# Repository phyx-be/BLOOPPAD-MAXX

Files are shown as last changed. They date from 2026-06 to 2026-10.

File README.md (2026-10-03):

# BLOOPAD-MAXX
an illuminated 8x8 keypad with a cheap USB microcontroller.

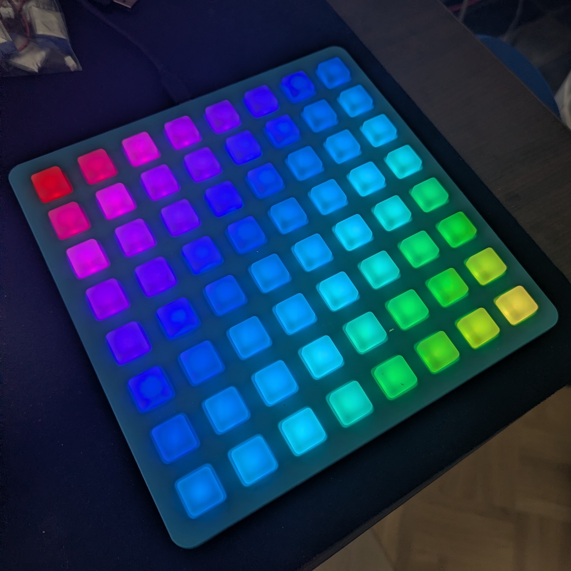
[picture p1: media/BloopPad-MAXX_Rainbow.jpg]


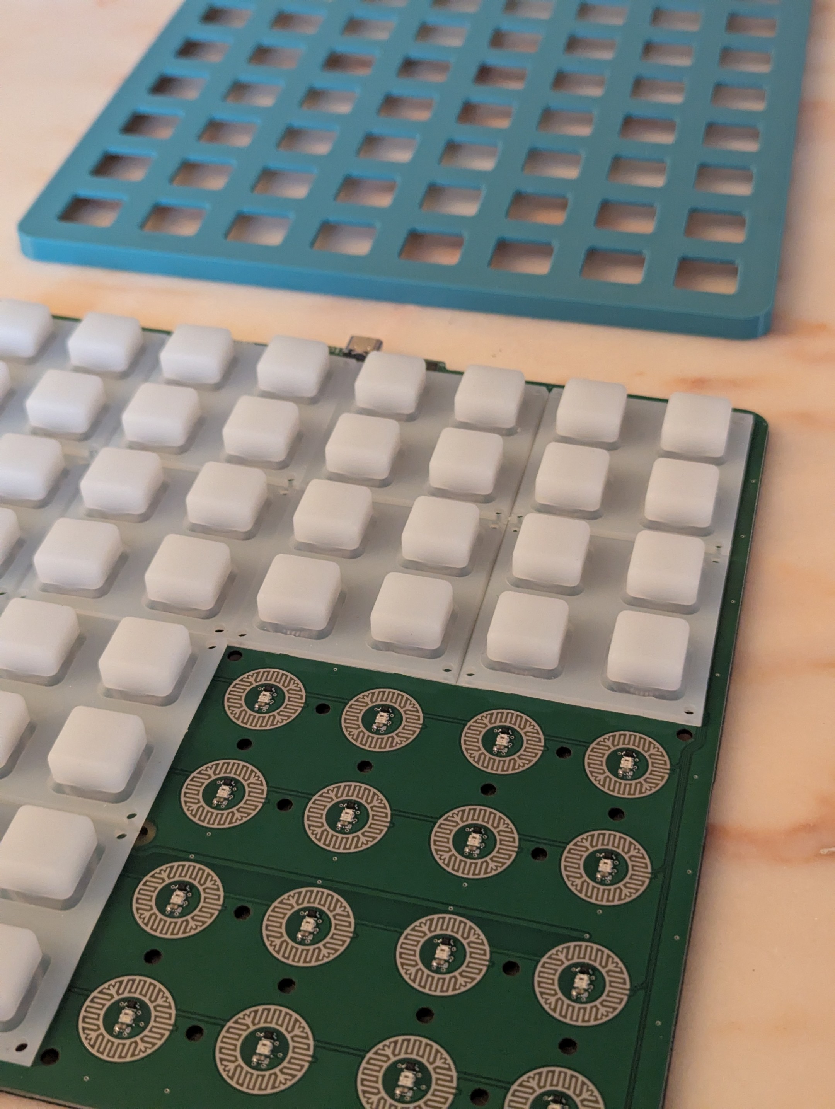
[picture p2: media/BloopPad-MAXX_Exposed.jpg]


## Hardware

There are 4 pins at the top to interact with the microcontroller. The two IO pins (PC18 and PC19) have multiple features, most notable are I²C, UART and SDI (serial 2-wire debug interface). The pins from left to right are as follows:
 * 5V
 * GND
 * PC18 - SDA - DIO - TX3 - PIOC IO0
 * PC19 - SCL - DCK - RX3

> Caution: BloopPad Maxx runs at 5V! So you might need to add a level translator for the I2C pins.

There are 64 WS2812c LEDs, each using around 25–30 mA, so we need around 2A from the host. To request 5V3A from the host, the 5K1 CC resistors are mounted on the USB-C connector. 

> ⚠️⚠️⚠️ The board however has no way of knowing if the USB port can supply that power. So limiting the total brightness of the LEDs might be required!

The button matrix is equiped with diodes to support [n-key rollover](https://en.wikipedia.org/wiki/Key_rollover)

### Rev 00

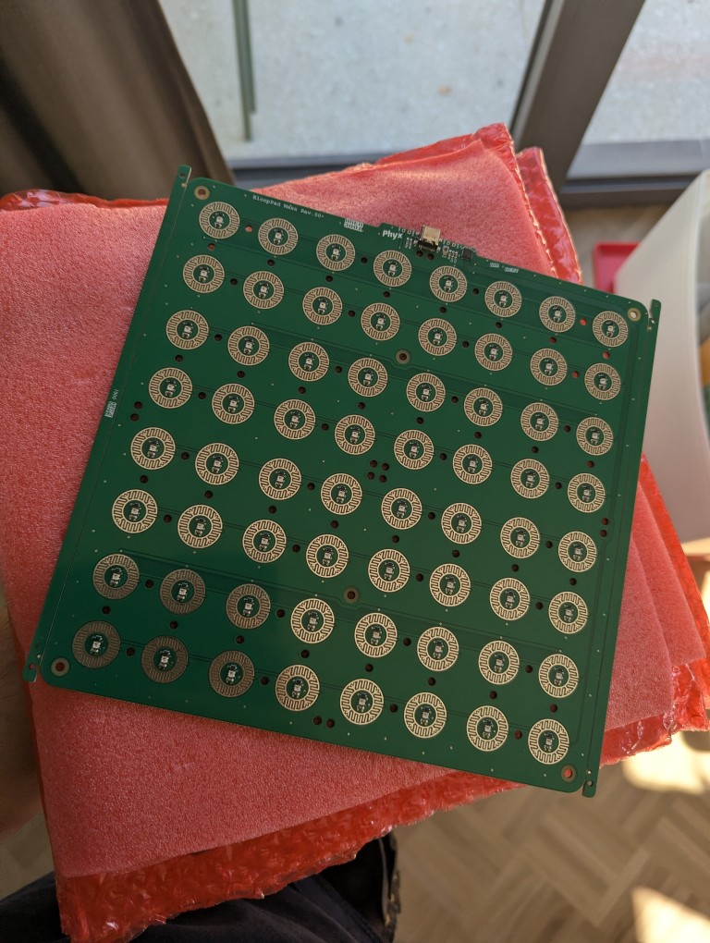
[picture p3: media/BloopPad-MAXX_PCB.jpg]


The initial board design, quickly cobbled together on an evening.

### Rev 01

Moved some traces away from the mounting holes closest to the USB-C connector so metal screws can be used.

## Firmware

This firmware runs on the [CH32X035](https://www.wch-ic.com/products/CH32X035.html) MCU of the BloopPad Maxx.

The firmware handles different functions:
 * Read the button matrix
 * Set the button RGB LEDs
 * Send MIDI CC messages over USB to a PC and over UART
 * Allow control from other devices using I2C (Caution: BloopPad Maxx runs at 5V!)

Please check the [schematics](hardware/BloopPadMaxx_00/OUTPUT/BloopPadMaxx_00.PDF) to get more details about how these peripherals are connected to the CH32X035 MCU.

### MIDI messages

The BloopPad Maxx sends and receives MIDI CC messages through USB or UART (baudrate of `115200 8N1`) to receive the button state or control the LEDs.

The MIDI CC (Control Change) messages related to the buttons are sent every time the state of one of the buttons changes. For each button, the value in the MIDI CC message is `0x7F` when the button is pressed and `0x00` when it is not pressed. Each button has the following CC number assigned:

|  | 0 | 1 | 2 | 3 | 4 | 5 | 6 | 7 |
|-|-|-|-|-|-|-|-|-|
| 0 | 0x00 | 0x01 | 0x02 | 0x03 | 0x04 | 0x05 | 0x06 | 0x07 |
| 1 | 0x10 | 0x11 | 0x12 | 0x13 | 0x14 | 0x15 | 0x16 | 0x17 |
| 2 | 0x20 | 0x21 | 0x22 | 0x23 | 0x24 | 0x25 | 0x26 | 0x27 |
| 3 | 0x30 | 0x31 | 0x32 | 0x33 | 0x34 | 0x35 | 0x36 | 0x37 |
| 4 | 0x40 | 0x41 | 0x42 | 0x43 | 0x44 | 0x45 | 0x46 | 0x47 |
| 5 | 0x50 | 0x51 | 0x52 | 0x53 | 0x54 | 0x55 | 0x56 | 0x57 |
| 6 | 0x60 | 0x61 | 0x62 | 0x63 | 0x64 | 0x65 | 0x66 | 0x67 |
| 7 | 0x70 | 0x71 | 0x72 | 0x73 | 0x74 | 0x75 | 0x76 | 0x77 |

De LEDs beneath the buttons can be controlled by sending a MIDI CC message with a value between 0x01 and 0x0A, which determines the color. Each LED has the following CC number assigned:

|  | 0 | 1 | 2 | 3 | 4 | 5 | 6 | 7 |
|-|-|-|-|-|-|-|-|-|
| 0 | 0x08 | 0x09 | 0x0A | 0x0B | 0x0C | 0x0D | 0x0E | 0x0F |
| 1 | 0x18 | 0x19 | 0x1A | 0x1B | 0x1C | 0x1D | 0x1E | 0x1F |
| 2 | 0x28 | 0x29 | 0x2A | 0x2B | 0x2C | 0x2D | 0x2E | 0x2F |
| 3 | 0x38 | 0x39 | 0x3A | 0x3B | 0x3C | 0x3D | 0x3E | 0x3F |
| 4 | 0x48 | 0x49 | 0x4A | 0x4B | 0x4C | 0x4D | 0x4E | 0x4F |
| 5 | 0x58 | 0x59 | 0x5A | 0x5B | 0x5C | 0x5D | 0x5E | 0x5F |
| 6 | 0x68 | 0x69 | 0x6A | 0x6B | 0x6C | 0x6D | 0x6E | 0x6F |
| 7 | 0x78 | 0x79 | 0x7A | 0x7B | 0x7C | 0x7D | 0x7E | 0x7F |

This is the mapping between the value and the RGB color of the LED to send using a MIDI CC message:

| Value | Red | Green | Blue | Name |
|-|-|-|-|-|
| 0x00 | 0x00 | 0x00 | 0x00 | LED off |
| 0x01 | 0xc5 | 0x0a | 0x08 | orange-red |
| 0x02 | 0x32 | 0xbe | 0x44 | teal |
| 0x03 | 0x42 | 0xd4 | 0xf4 | yellow-green |
| 0x04 | 0xf8 | 0xd2 | 0x00 | warm white |
| 0x05 | 0x00 | 0x44 | 0xff | blue |
| 0x06 | 0xaf | 0x00 | 0xcc | cyan |
| 0x07 | 0xfc | 0xa6 | 0xd7 | white |
| 0x08 | 0xf2 | 0xf2 | 0xff | bright white |
| 0x09 | 0xff | 0x80 | 0x00 | green |

To control the full RGB color of each LED individually using MIDI, we need 4 bytes (LED index, red, green, blue), which is more than the 3 bytes that are available in a Control Change message. That is why we use MIDI System Exclusive (SysEx) messages for this. The format is:

```
F0 13 37 <led> <red> <green> <blue> F7
```

The first byte `0xF0` indicates the start of a SysEx MIDI message. Byte 2 and 3 indicate a manufacturer ID (`0x1337` in our case). The 4th byte is the LED index as described above. The next 3 bytes are the `red`, `green` and `blue` bytes. Their value can be max `0x7F` in a MIDI SysEx message, so make sure you right-shift your RGB data before sending. The last byte `0xF7` indicates the end of the SysEx message.

#### Reboot into the bootloader

One SysEx message is not an LED update:

```
F0 13 37 00 42 4F 4F F7
```

It reboots the pad into WCH's ISP bootloader, so a reflash needs neither the boot button nor a replug - see "Flashing" below. `0x00` sits where an LED frame carries its LED index, and `0x00` is never a valid index (the low nibble of an index is always `8`-`15`), so the two cannot be confused. The trailing `42 4F 4F` ("BOO") makes the command a deliberate eight-byte sequence rather than a short one that might turn up by chance. While the pad is in the bootloader, all LEDs are dim purple.

The command is handled in the game menu and in MIDI mode, not while a game is running. Two cautions:

- **Any MIDI software on the host could send it.** A spurious trigger is recoverable without tools, because the bootloader runs the application again after a few seconds if no upload starts - it costs a reboot, not a brick.
- **The host must start the upload immediately**, for the same reason.

### I2C

The BloopPad Maxx has I2C address `0x55` and uses the following registers to interface/control with its connected peripherals:

| Address (hex) | Name | Access | Bytes | description |
|-|-|-|-|-|
| 0x00 | Version number | R | 3 | Reports the firmware version number |
| 0x03 | Button states | R | 8 | Reports the button states |
| 0x0b | Button RGB LEDs | R/W | 192 | The RGB value of the button leds |

### Building

Use [platformio](https://platformio.org) to build this project. You should install the [ch32v platform package](https://github.com/Community-PIO-CH32V/platform-ch32v) as well. Follow [these instructions](https://pio-ch32v.readthedocs.io/en/latest/installation.html) to do so. If you use the command line, build using:

```
pio run -e debug
```

### Flashing

The easiest way is [the web playground](https://drskunk.github.io/blooppad-maxx-playground/): open its **Flash firmware** panel, connect the pad, and press Flash. It sends the SysEx above to reboot the pad into ISP, then writes and verifies over WebUSB - no boot button, no replug.

From a shell with [wchisp](https://github.com/ch32-rs/wchisp): send `F0 13 37 00 42 4F 4F F7` to the pad with any MIDI tool to put it into ISP, or - if the firmware does not run or does not enumerate - disconnect the USB cable, hold the boot button on the board, and reconnect it. Then run:

```
wchisp flash <path to the firmware.bin file>
```

Or using Platformio:

```
pio run -e debug -t upload
```

## Playing

Beside playing with the built-in apps, you can thinker with the board using the [the web playground](https://drskunk.github.io/blooppad-maxx-playground/) or use it as a sequencer or sample pad on the [Fri3d Scatcher](https://fri3dcamp.github.io/fri3d-scratcher/) website.

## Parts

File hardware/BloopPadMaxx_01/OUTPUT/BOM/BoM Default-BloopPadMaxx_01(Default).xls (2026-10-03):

Bill of Materials |  |  | BloopPad Maxx
Project: |  | BloopPadMaxx_01.PrjPcb
Revision: |  | 01
Variant: |  | Default
Creation Date: | 11/09/2026 | 16:13
Print Date: | 2026-09-11 | 16:13:12
Footprint | Comment | LibRef | Designator | Value | Description | Supplier 1 | Supplier Part Number 1 | Supplier 2 | Supplier Part Number 2 | Supplier 3 | Supplier Part Number 3 | Quantity
C0603_N |  | CAP # 100nF 16V 0603 | C1, C2, C3, C4, C5, C6, C7, C8, C9, C10, C11, C12, C13, C14, C15, C16, C17, C19, C20, C21, C22, C23, C24, C25, C26, C27, C28, C29, C30, C31, C32, C33, C34, C35, C36, C37, C38, C39, C40, C41, C42, C43, C44, C45, C46, C47, C48, C49, C50, C51, C52, C53, C54, C55, C56, C57, C58, C59, C60, C61, C62, C63, C64, C65, C66 | 100nF 16V | CAP # 100nF 16V 0603 | LCSC | C282519 |  |  | Generic | 100nF 16V 0603 X7R | 65
C0603_N |  | CAP # 1uF 16V 0603 | C18 | 1uF 16V | CAP # 1uF 16V 0603 | Farnell | 2320814 | LCSC | C1592 | Generic | 1uF 16V 0603 X7R | 1
CZ20_4x4 | Campzone 2020 4x4 silicone keypad | SW # CZ20 4x4 | CZ1, CZ2, CZ3, CZ4 | CZ20 4x4 | SW # CZ20 4x4 | STOCK |  |  |  |  |  | 4
LED_2022_WS2812B | WS2812 based digital RGB LED 2022 package | LED # RGB WS2812B-2022 | D1, D2, D3, D4, D69, D70, D71, D72, D73, D74, D75, D76, D77, D78, D79, D80, D81, D82, D83, D84, D85, D86, D87, D88, D89, D90, D91, D92, D93, D94, D95, D96, D97, D98, D99, D100, D101, D102, D103, D104, D105, D106, D107, D108, D109, D110, D111, D112, D113, D114, D115, D116, D117, D118, D119, D120, D121, D122, D123, D124, D125, D126, D127, D128 | WS2812B-2022 | LED # RGB WS2812B-2022 | LCSC | C965555 |  |  |  |  | 64
SOD-323_AC | 1N4148W 75V 200mA 1.25Vf@150mA | DIO # 1N4148W SOD-323 | D5, D6, D7, D8, D9, D10, D11, D12, D13, D14, D15, D16, D17, D18, D19, D20, D21, D22, D23, D24, D25, D26, D27, D28, D29, D30, D31, D32, D33, D34, D35, D36, D37, D38, D39, D40, D41, D42, D43, D44, D45, D46, D47, D48, D49, D50, D51, D52, D53, D54, D55, D56, D57, D58, D59, D60, D61, D62, D63, D64, D65, D66, D67, D68 | 1N4148W | DIO # 1N4148W SOD-323 | LCSC | C2904852 | LCSC | C917117 | LCSC | C909968 | 64
XUNPU-TYPEC-304S-ACP16 | USB 2.0 C Reversible Receptacle Horizontal full SMD | USB # C 2.0 RCPT TYPEC-304S-ACP16 | J1 | TYPEC-304S-ACP16 | USB # C 2.0 RCPT TYPEC-304S-ACP16 | LCSC | C5187472 | LCSC | C2927040 | LCSC | C5156603 | 1
R0603_N |  | RES # 10K 0603 | R1 | 10K | RES # 10K 0603 | Farnell | 2502397 | LCSC | C25804 | Generic | 10K 1% 0603 | 1
R0603_N |  | RES # 5K1 0603 | R2, R3 | 5K1 | RES # 5K1 0603 | Farnell | 2845922 | LCSC | C112314 | Generic | 5K1 1% 0603 | 2
OMR_B3U-1000P | LP SMD tact sw 3x2.5mm | SW # TACT mini 3x2.5 mm B3U-1000P | SW1 | B3U-1000P | SW # TACT mini 3x2.5 mm B3U-1000P | LCSC | C561514 | LCSC | C231329 | Digi-Key | SW1020CT-ND | 1
QFN_28_4.0x4.0_P0.4 | WCH CH32X035G8U6 QFN28 RISC-V 32-bit MCU, 62KB Flash, 10KB RAM, USB PD | RISCV # CH32X035G8U6 | U1 | CH32X035G8U6 | RISCV # CH32X035G8U6 | LCSC | C7437027 |  |  |  |  | 1
 |  |  |  |  |  |  |  |  |  |  |  | 204
Approved |  | Notes

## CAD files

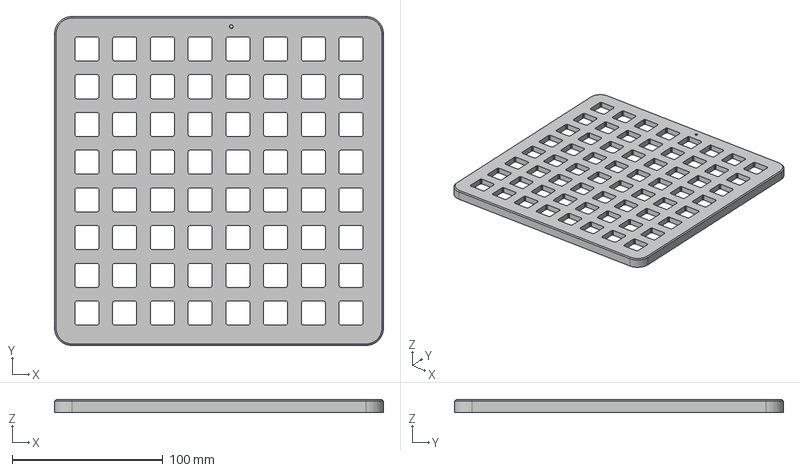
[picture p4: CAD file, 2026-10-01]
mechanical/BloopPadMaxx_00_inserts.step
218.0 x 218.0 x 8.60 mm
TopCover
BottomCover

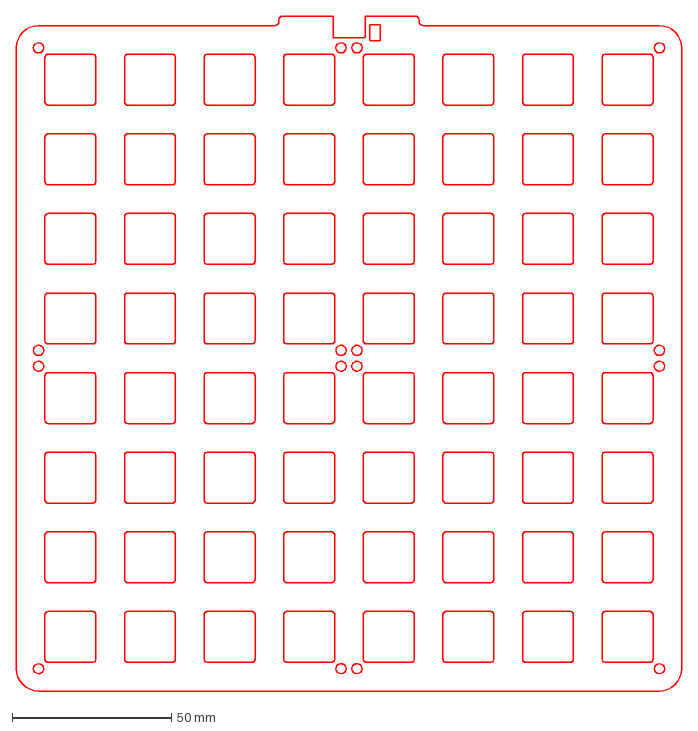
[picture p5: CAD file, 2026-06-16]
mechanical/Top_Cover.dxf
209.0 x 212.0 mm

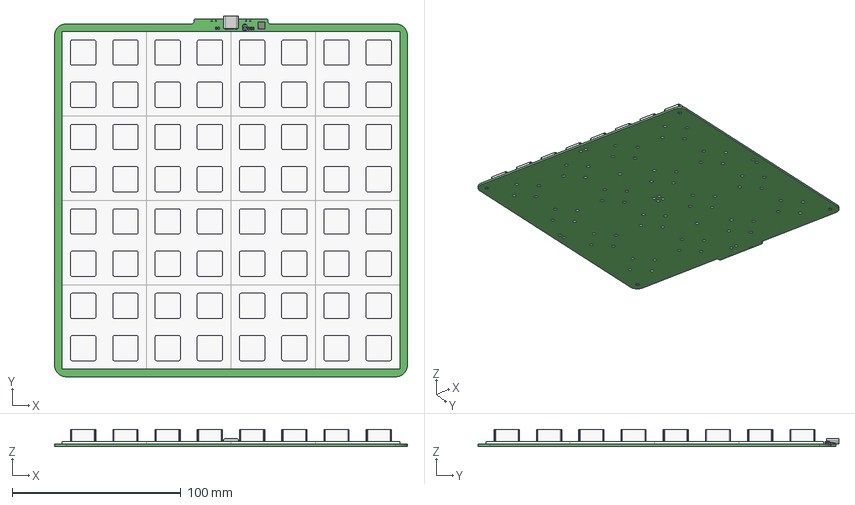
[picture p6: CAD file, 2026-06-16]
mechanical/BloopPadMaxx_00.step
209.0 x 213.5 x 10.3 mm
Extruded x 464
B3U-1000P
Thermal Shape
R0603 x 3
HRO TYPE-C-31-M-12
User Library-SOD323-1 x 64
C0603 x 66

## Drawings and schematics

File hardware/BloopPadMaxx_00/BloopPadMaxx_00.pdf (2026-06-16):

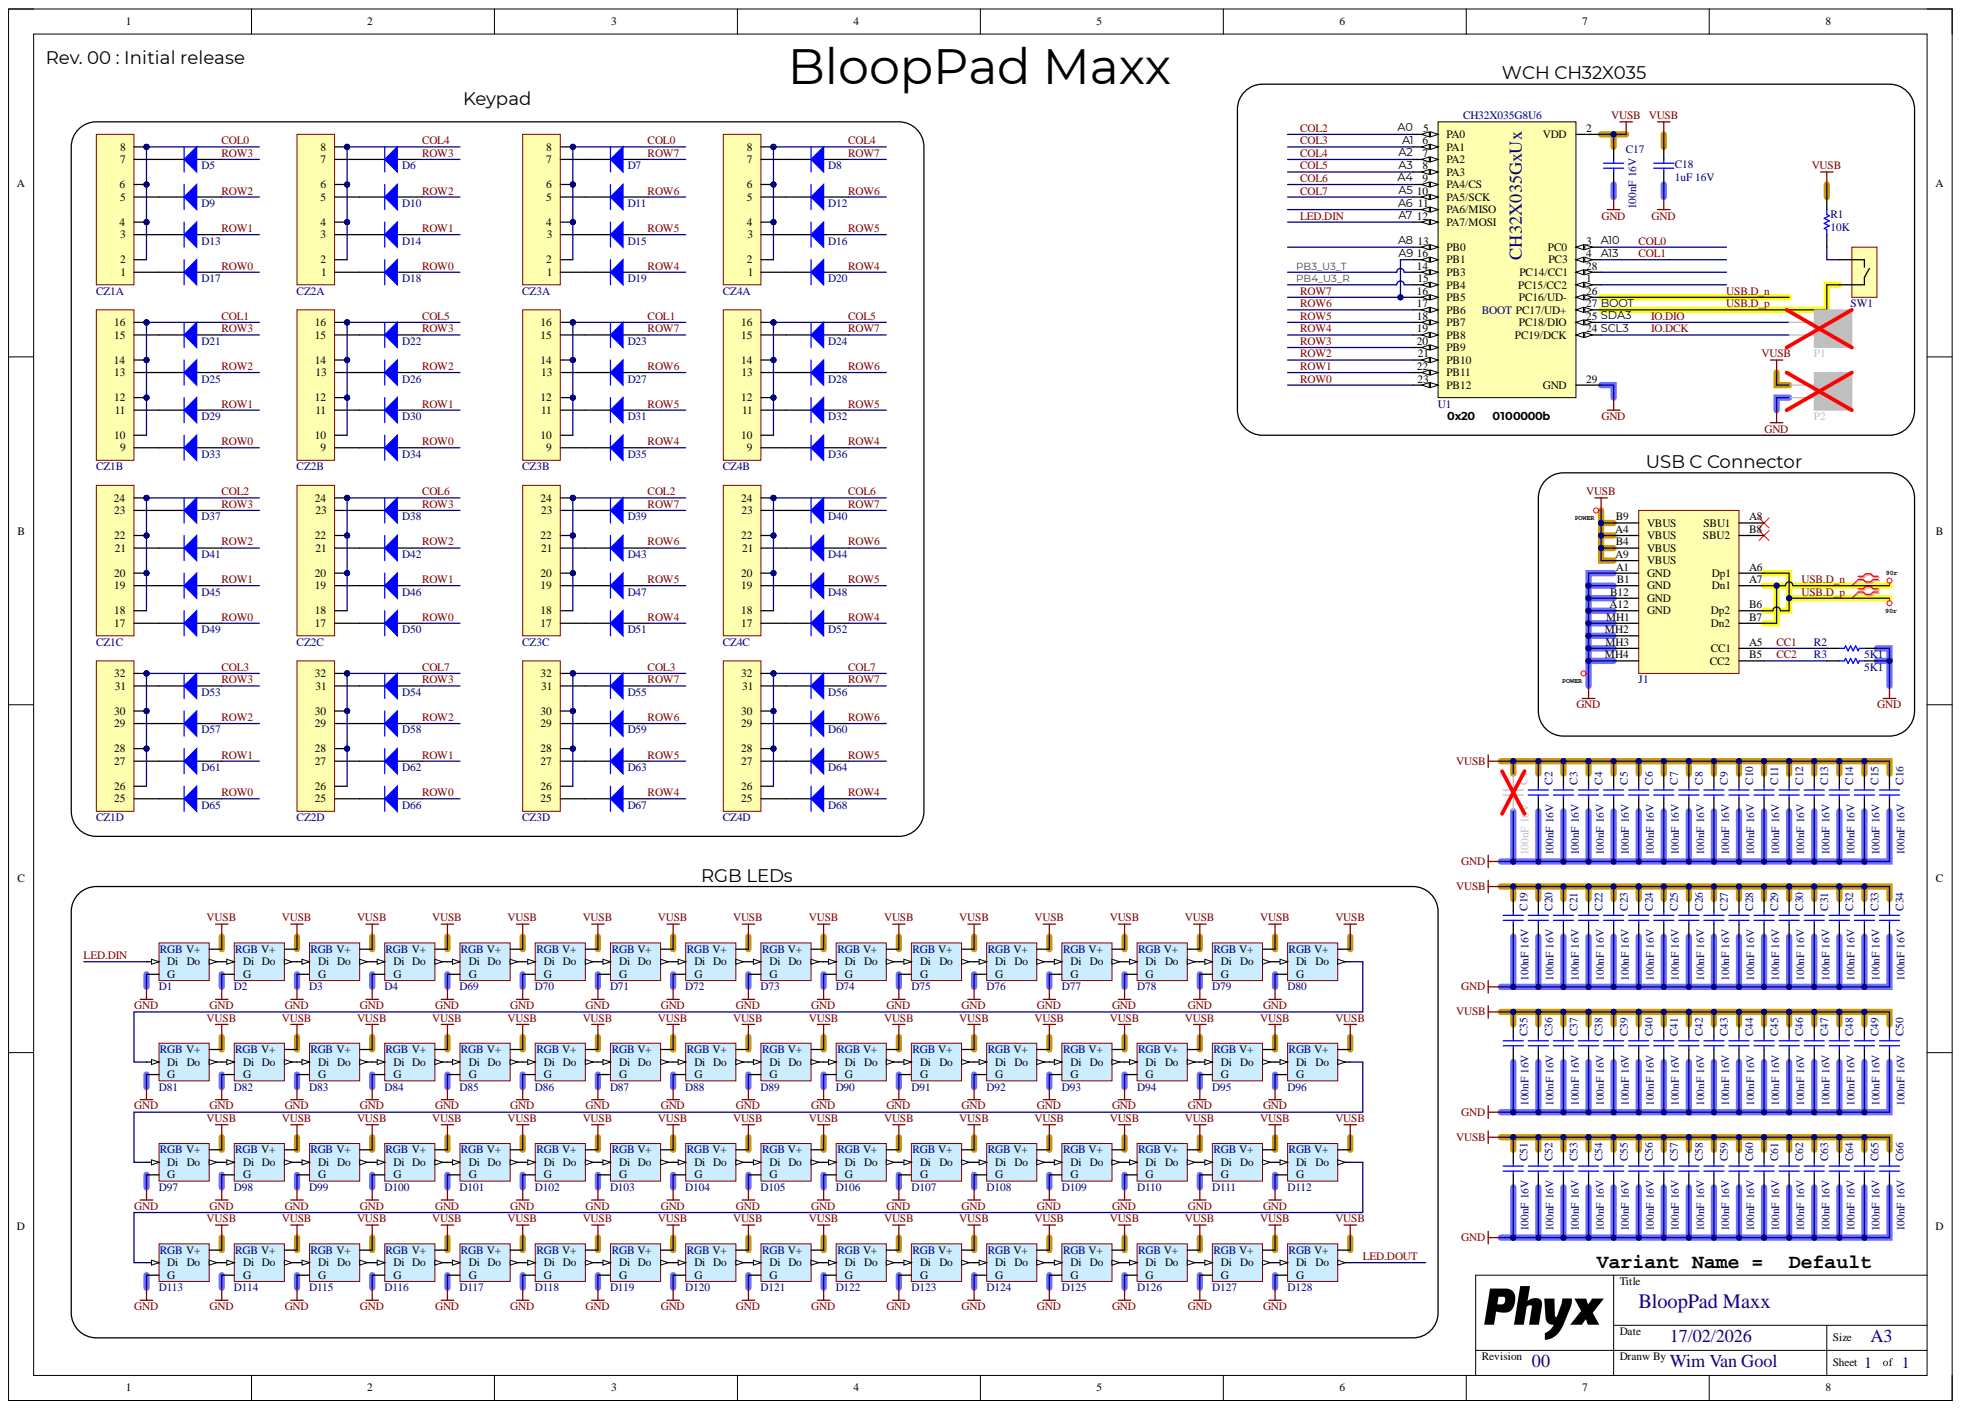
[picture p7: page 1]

BloopPad Maxx Rev. 00 : Initial release

VBUS B4
VBUS A9

GND A12
MH1
MH2
MH3
MH4 | CC2 R3 5K1

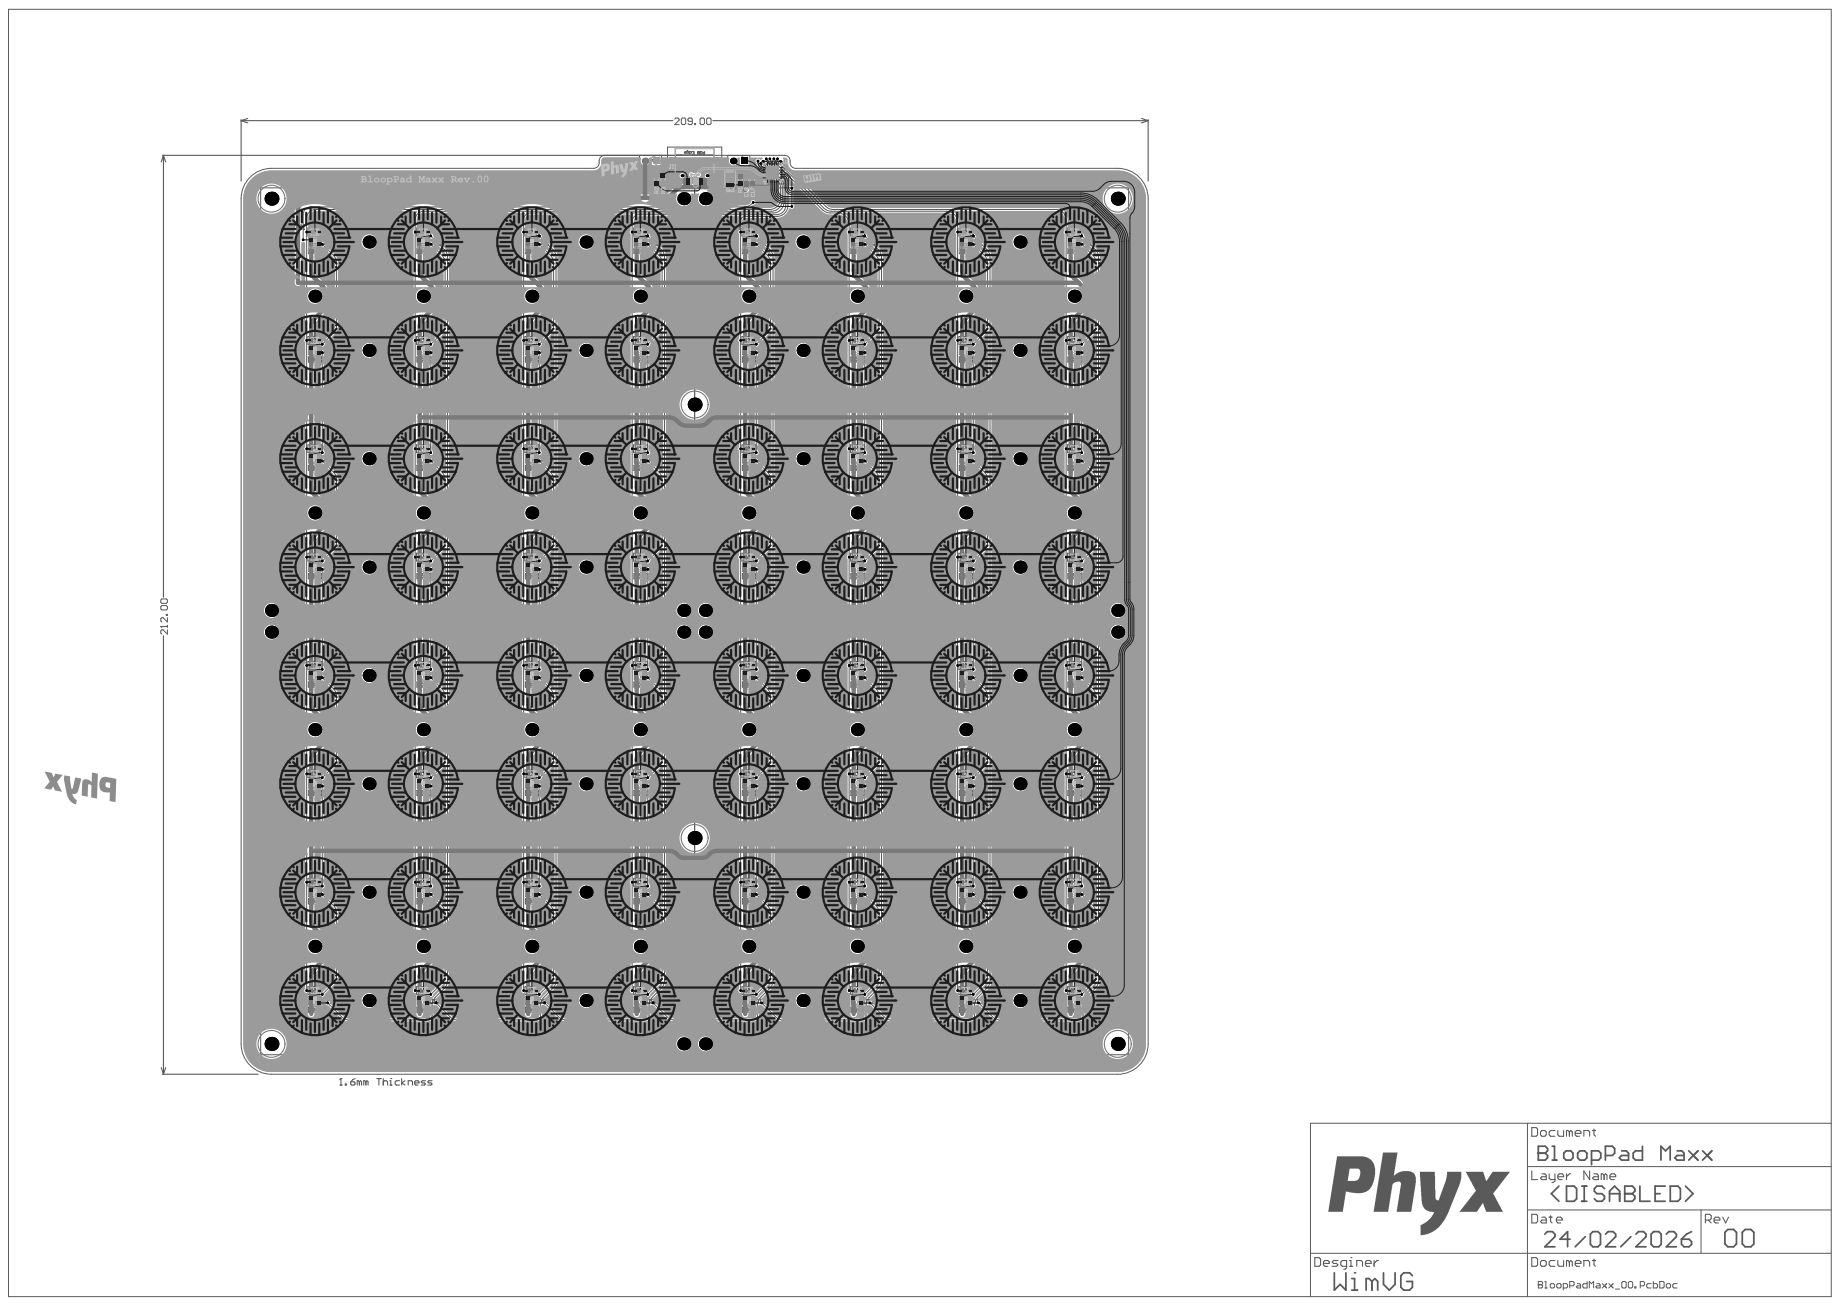
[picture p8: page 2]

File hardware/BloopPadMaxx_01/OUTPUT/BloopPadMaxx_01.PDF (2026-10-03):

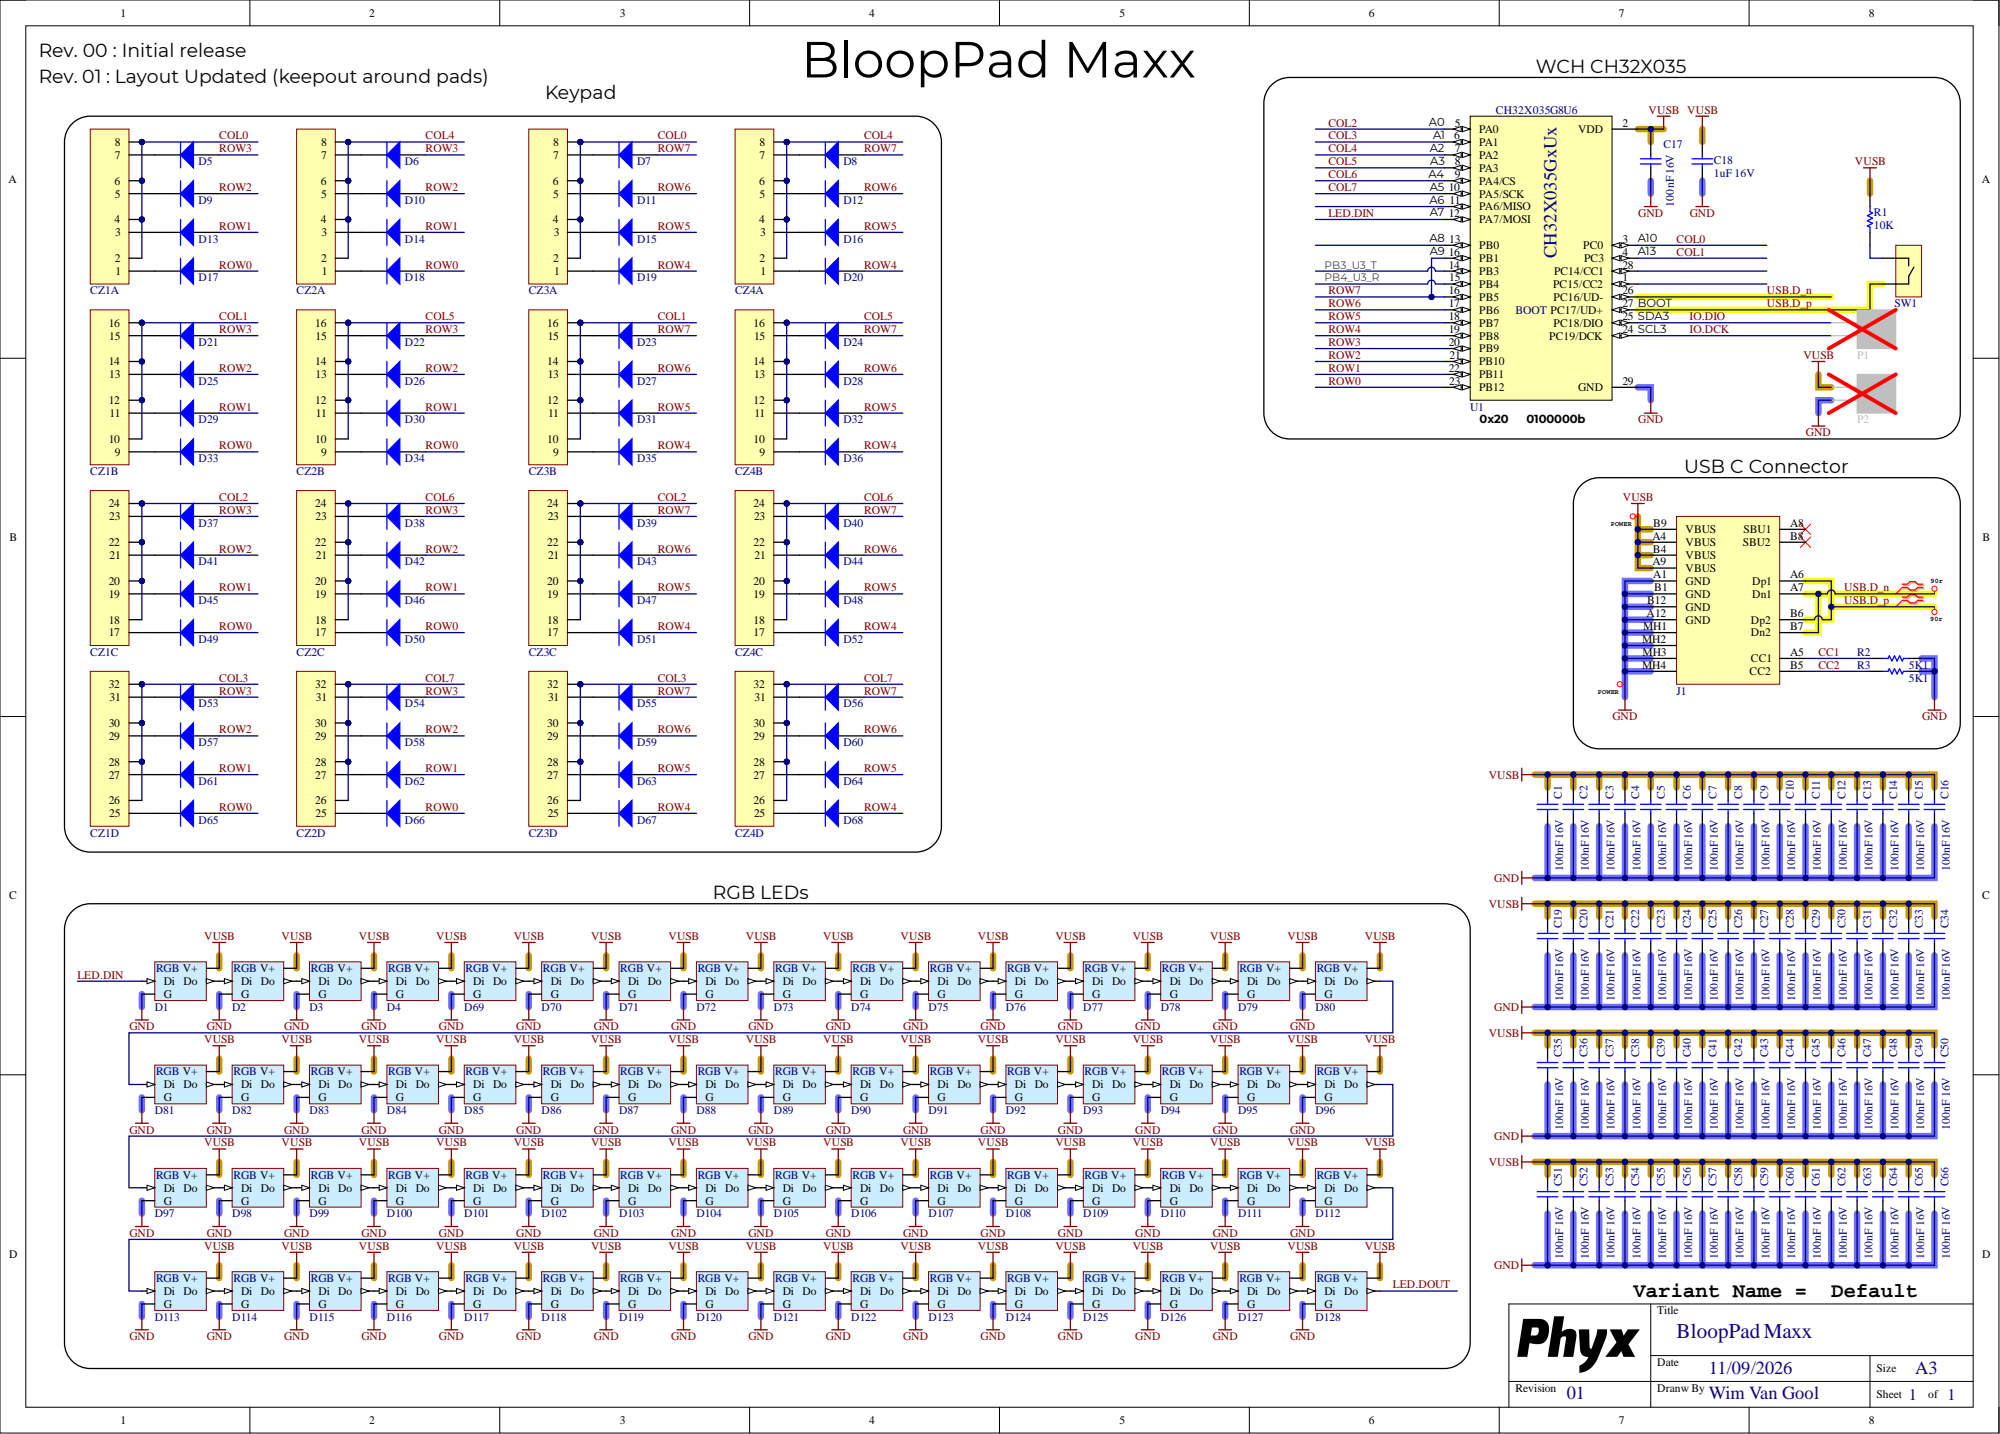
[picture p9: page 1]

BloopPad Maxx Rev. 00 : Initial release
Rev. 01 : Layout Updated (keepout around pads)

VBUS B4
VBUS A9

GND A12
MH1
MH2
MH3
MH4 | CC2 R3 5K1

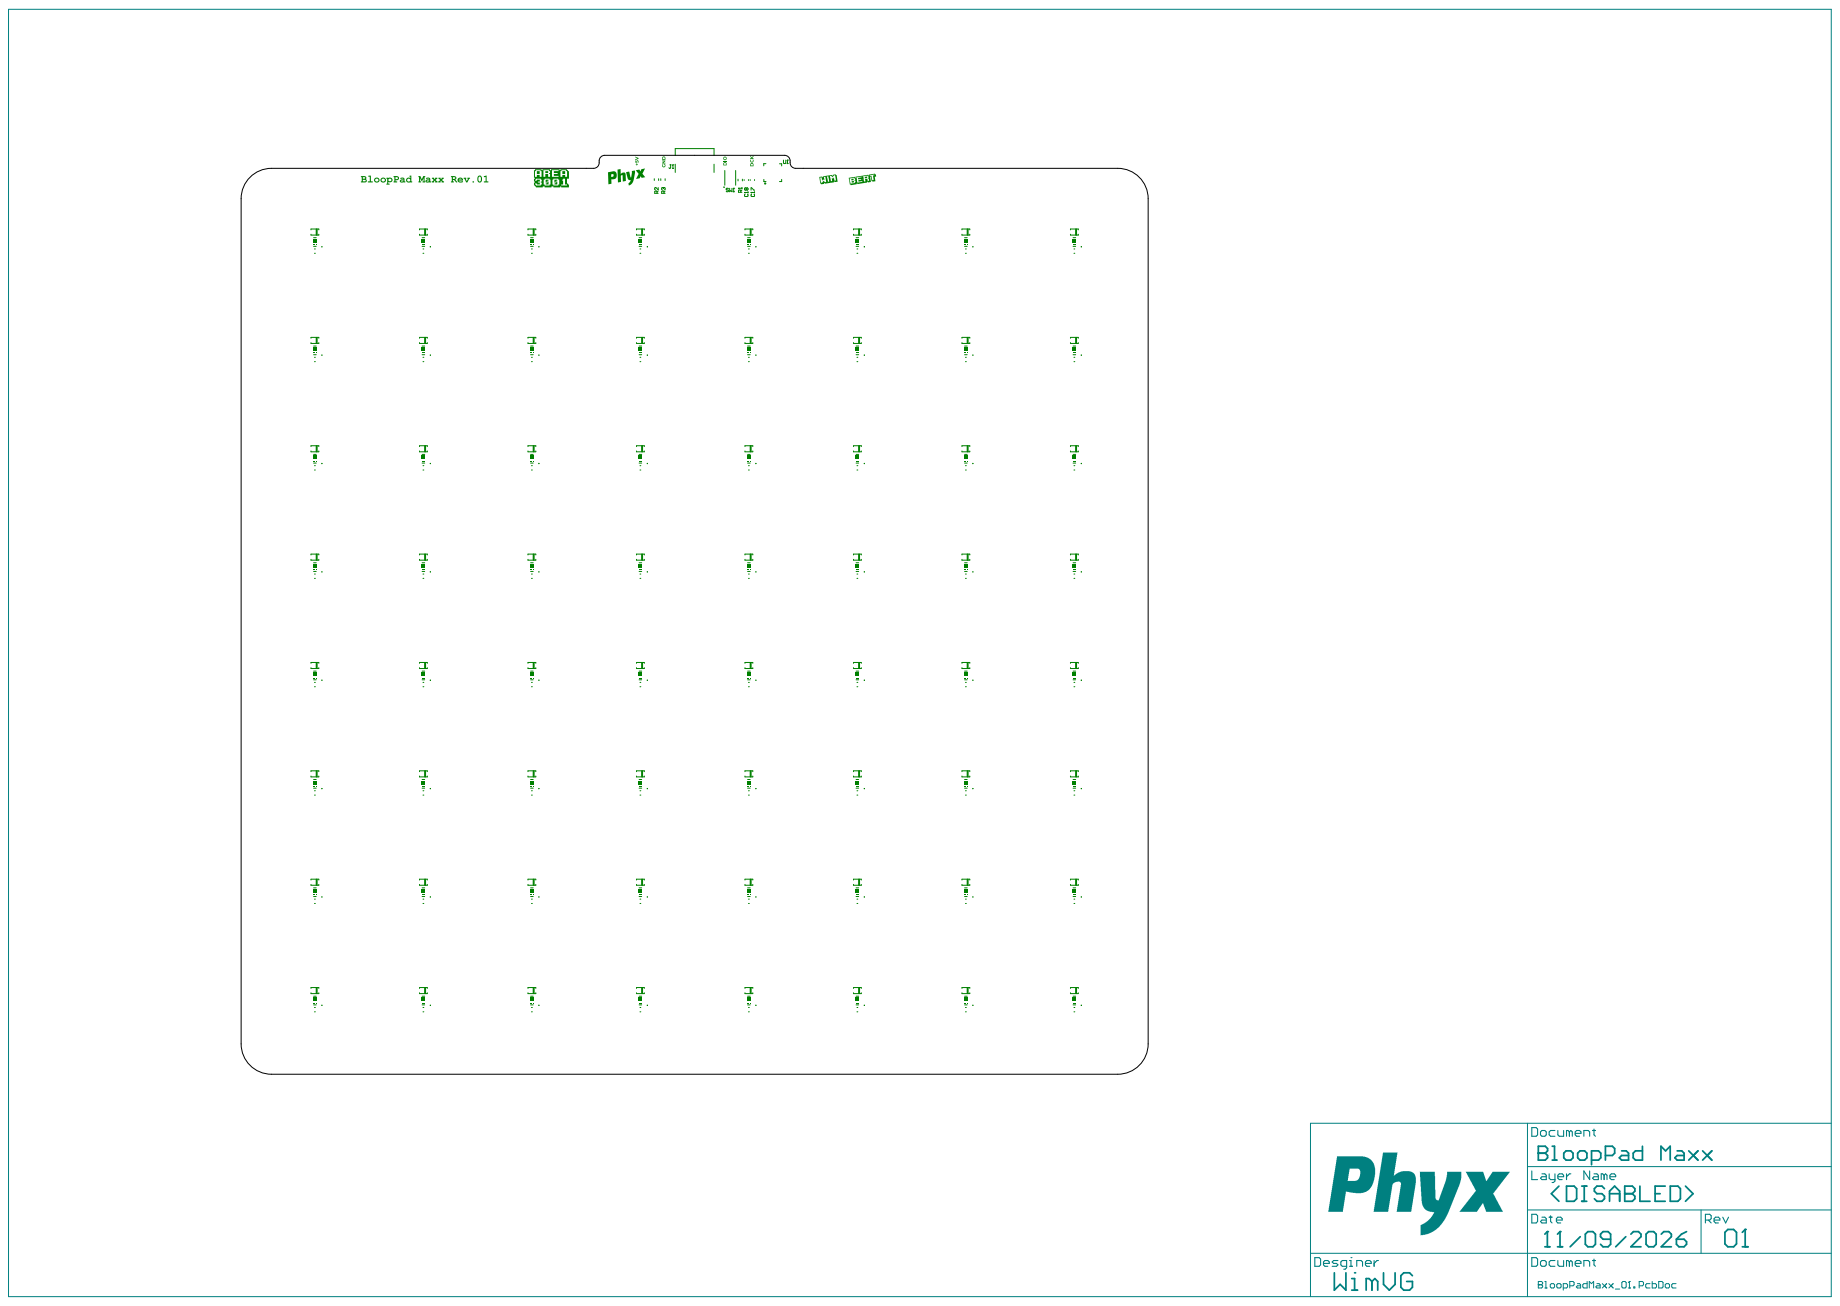
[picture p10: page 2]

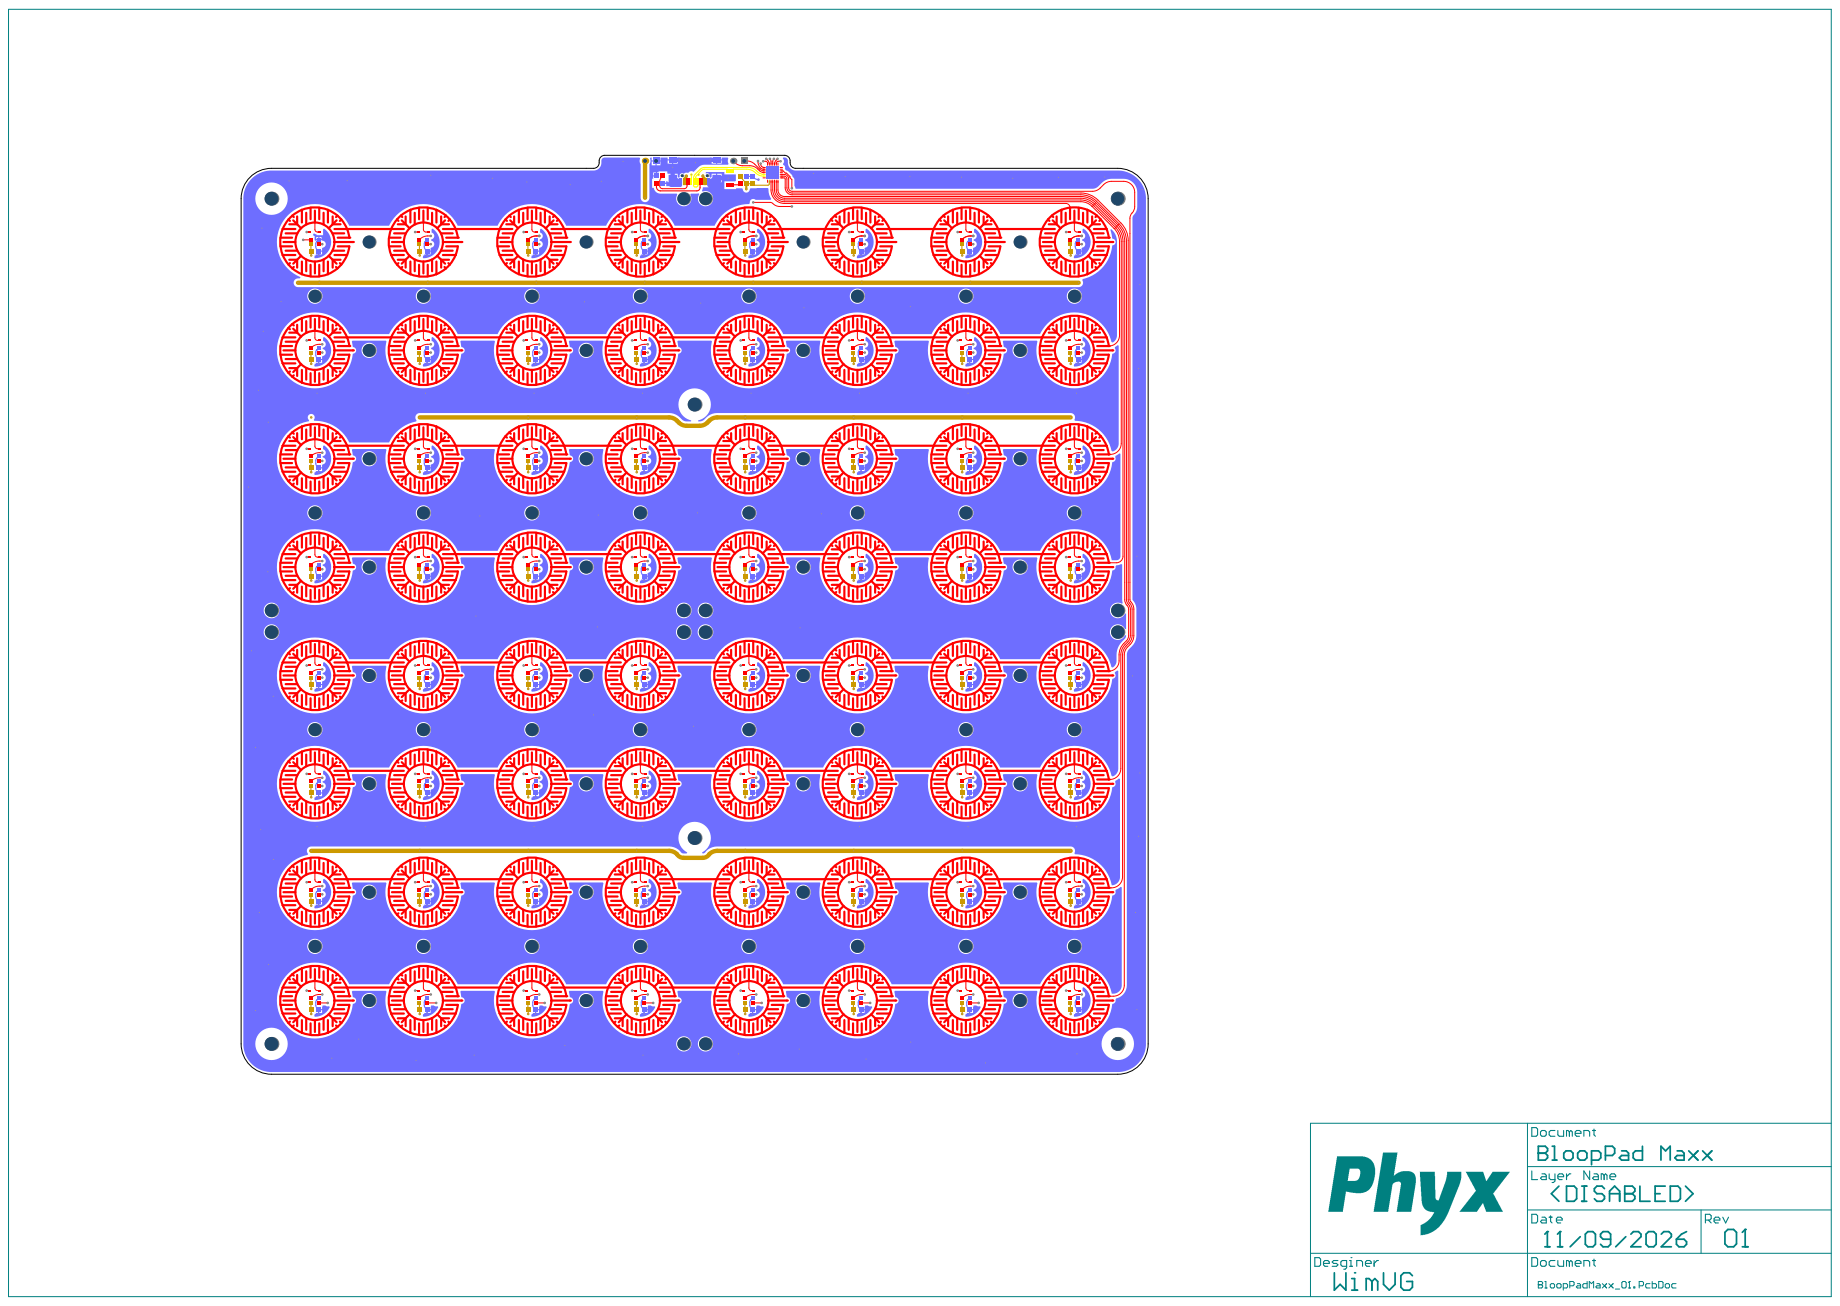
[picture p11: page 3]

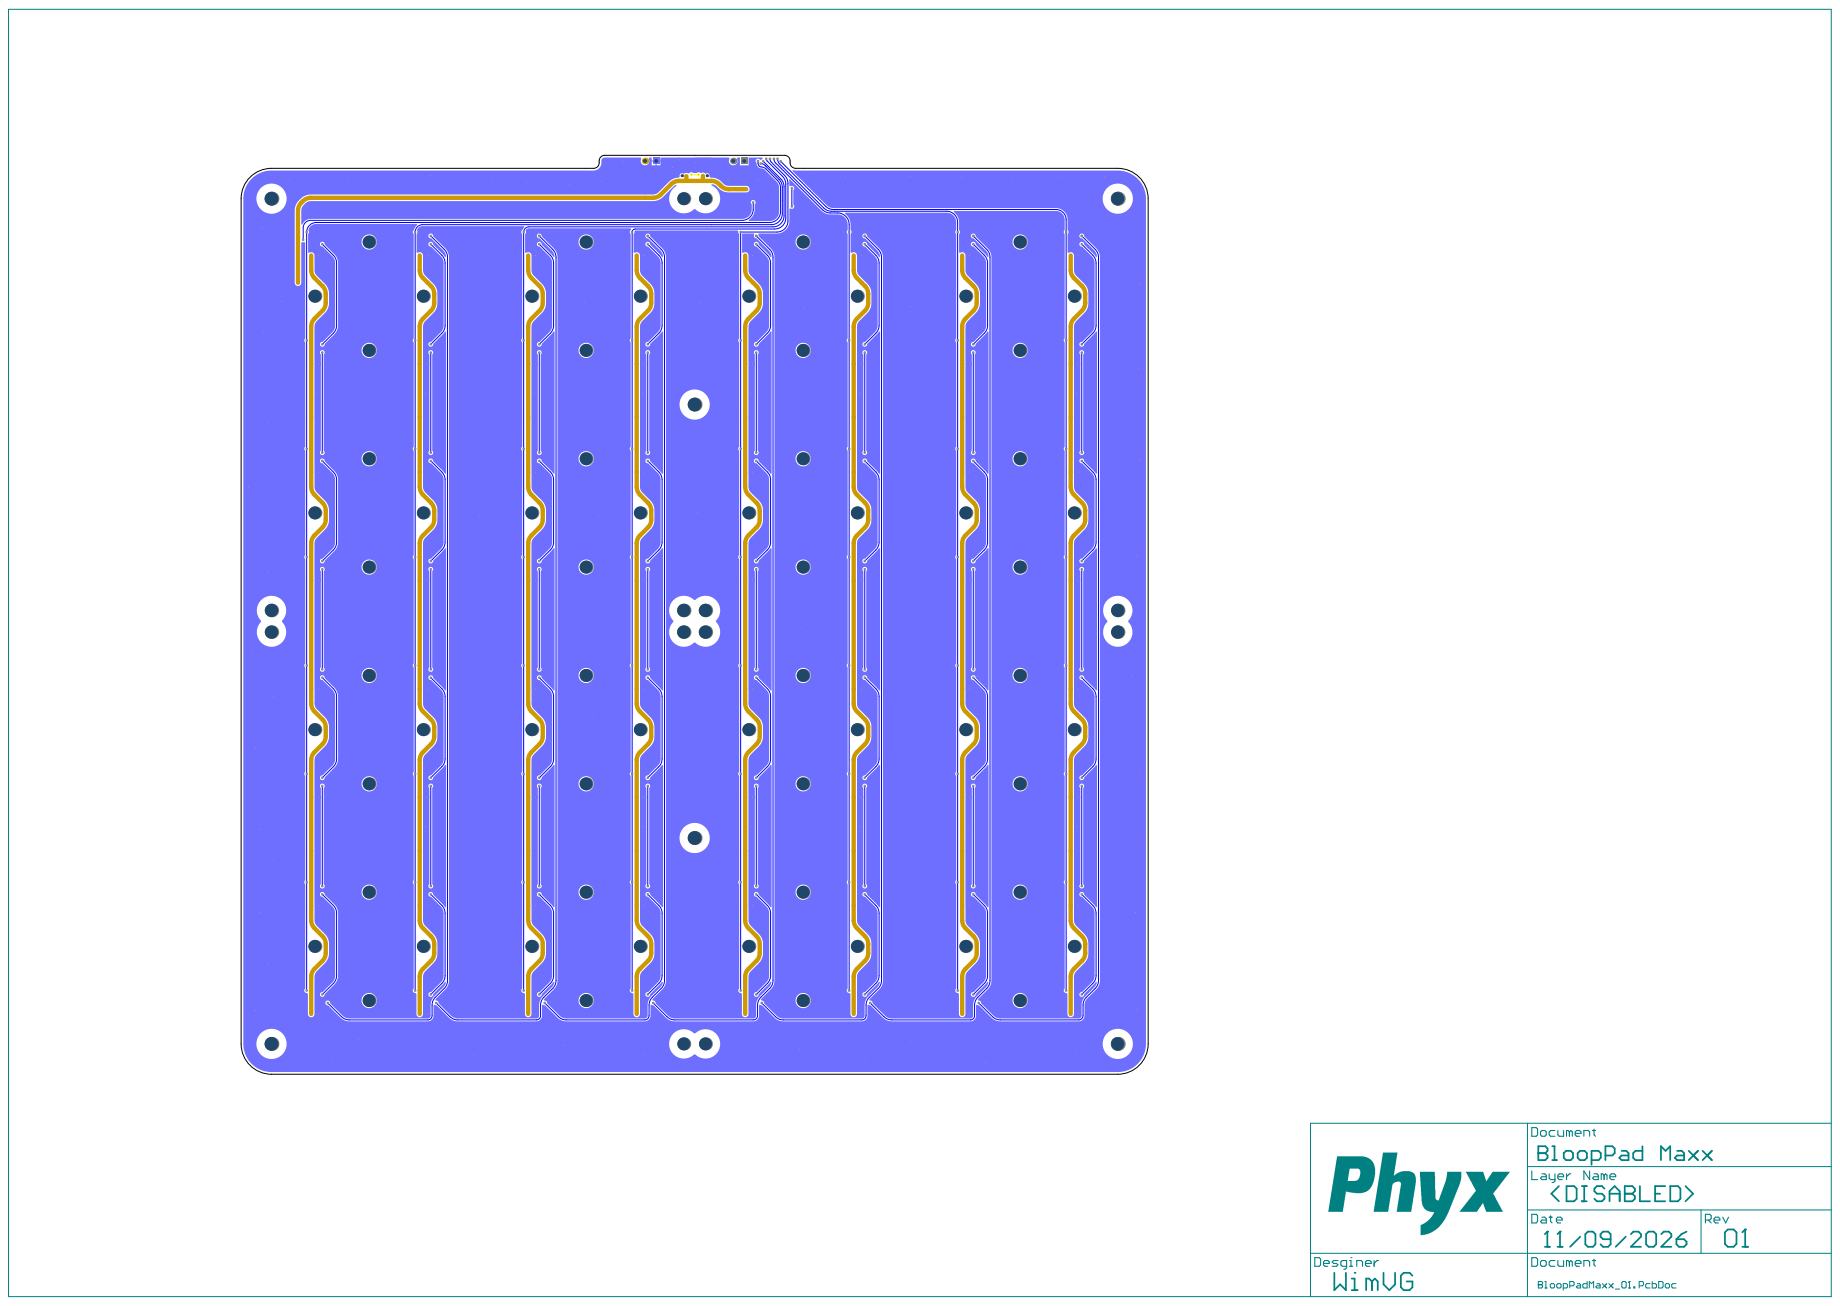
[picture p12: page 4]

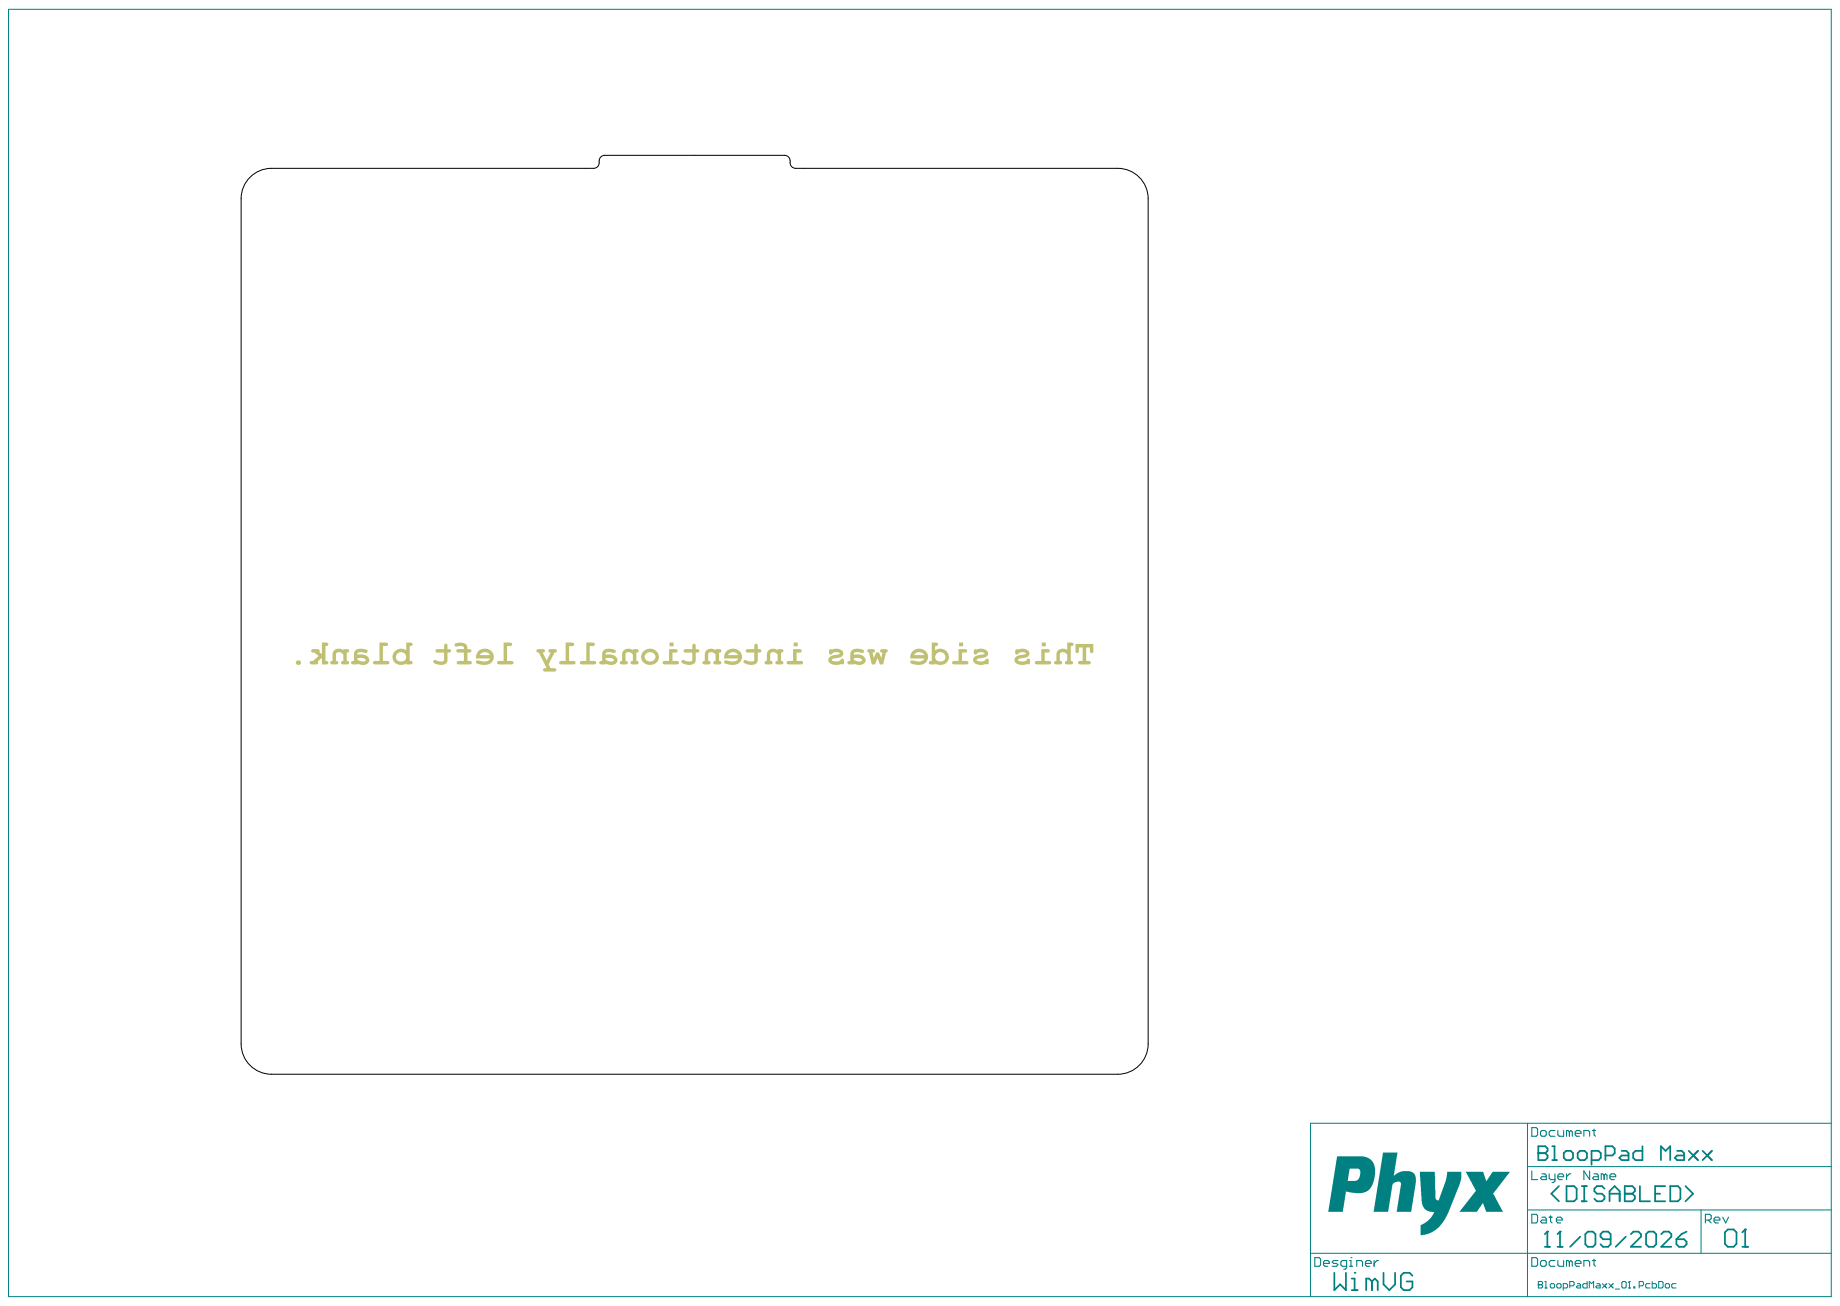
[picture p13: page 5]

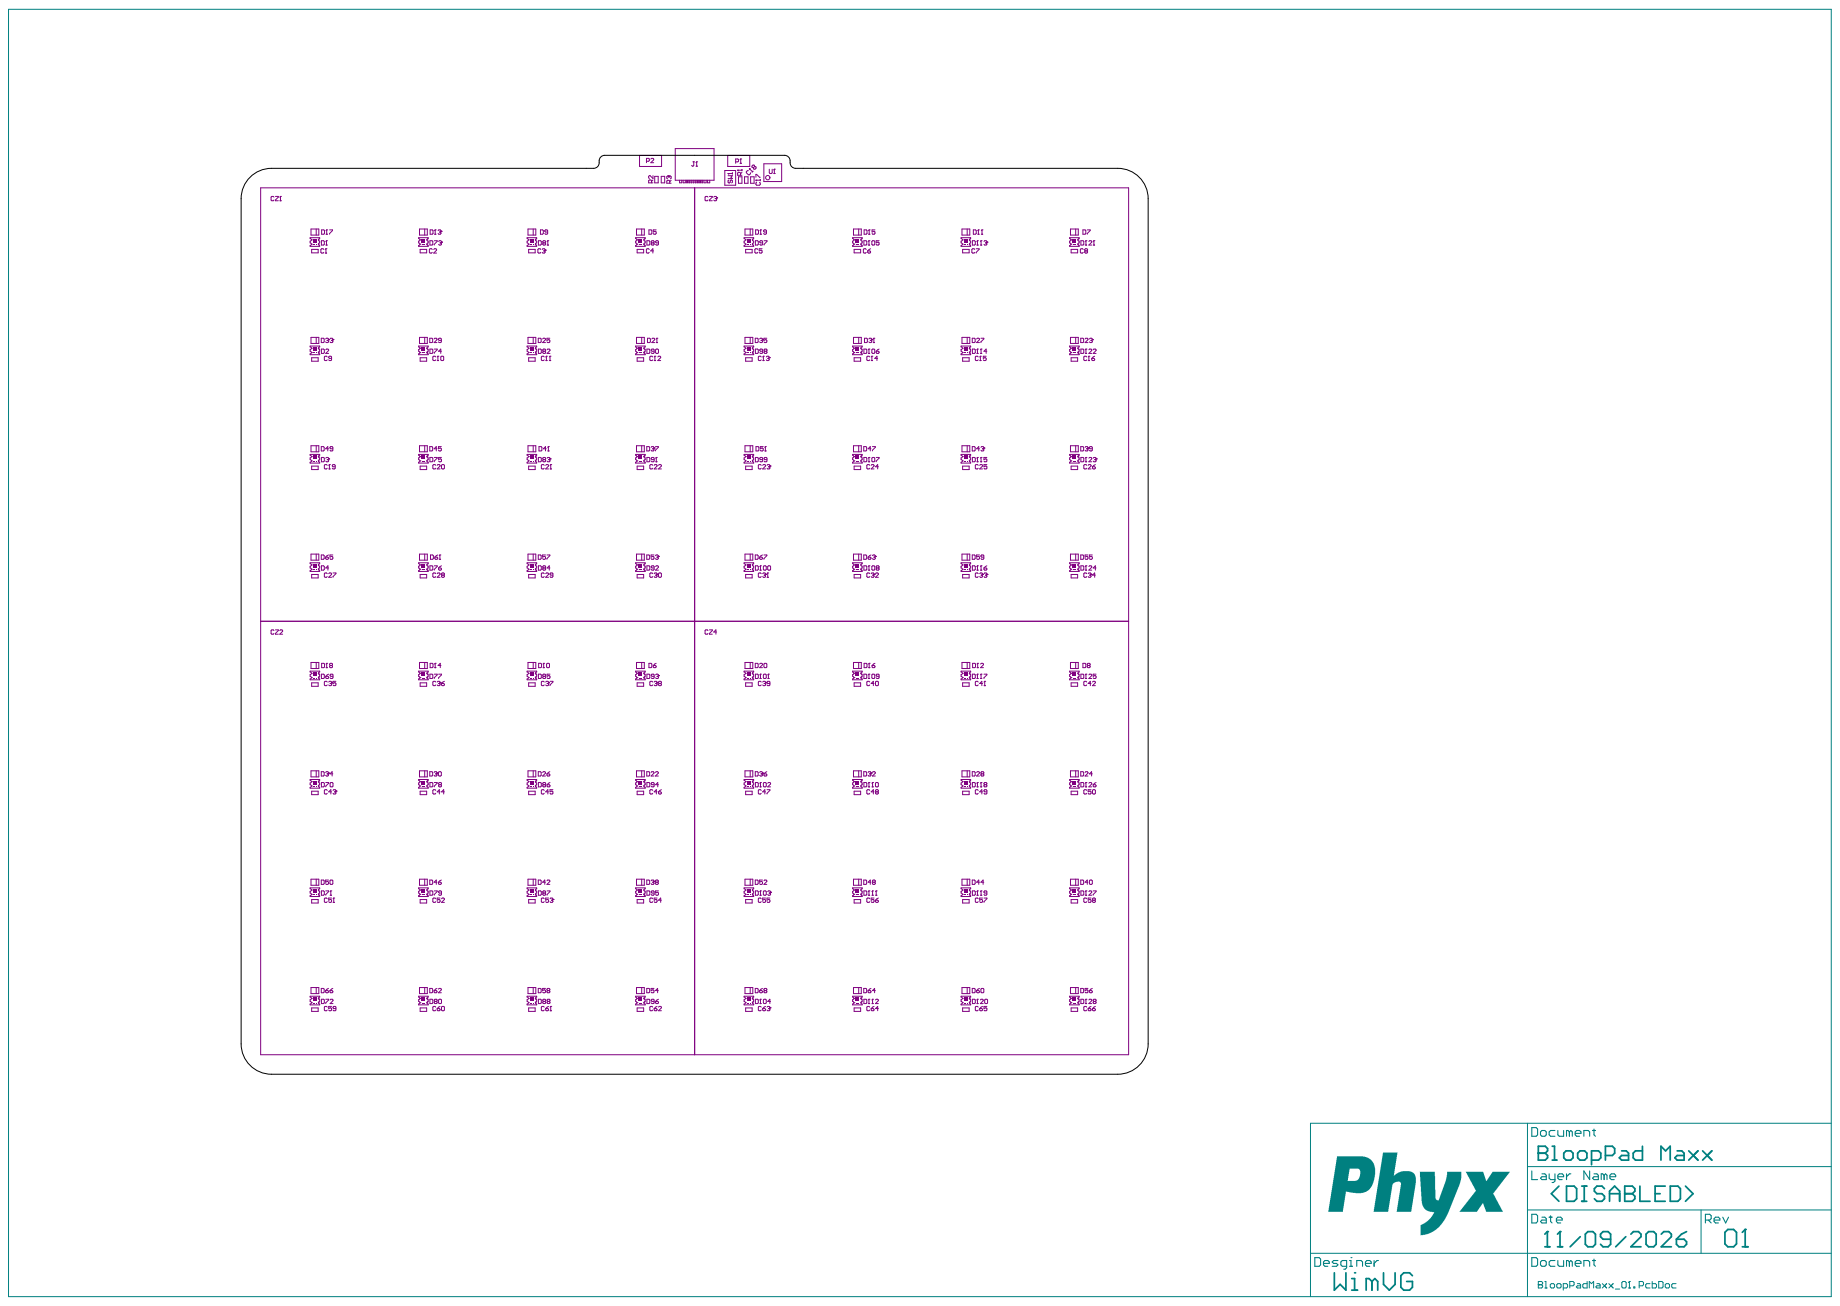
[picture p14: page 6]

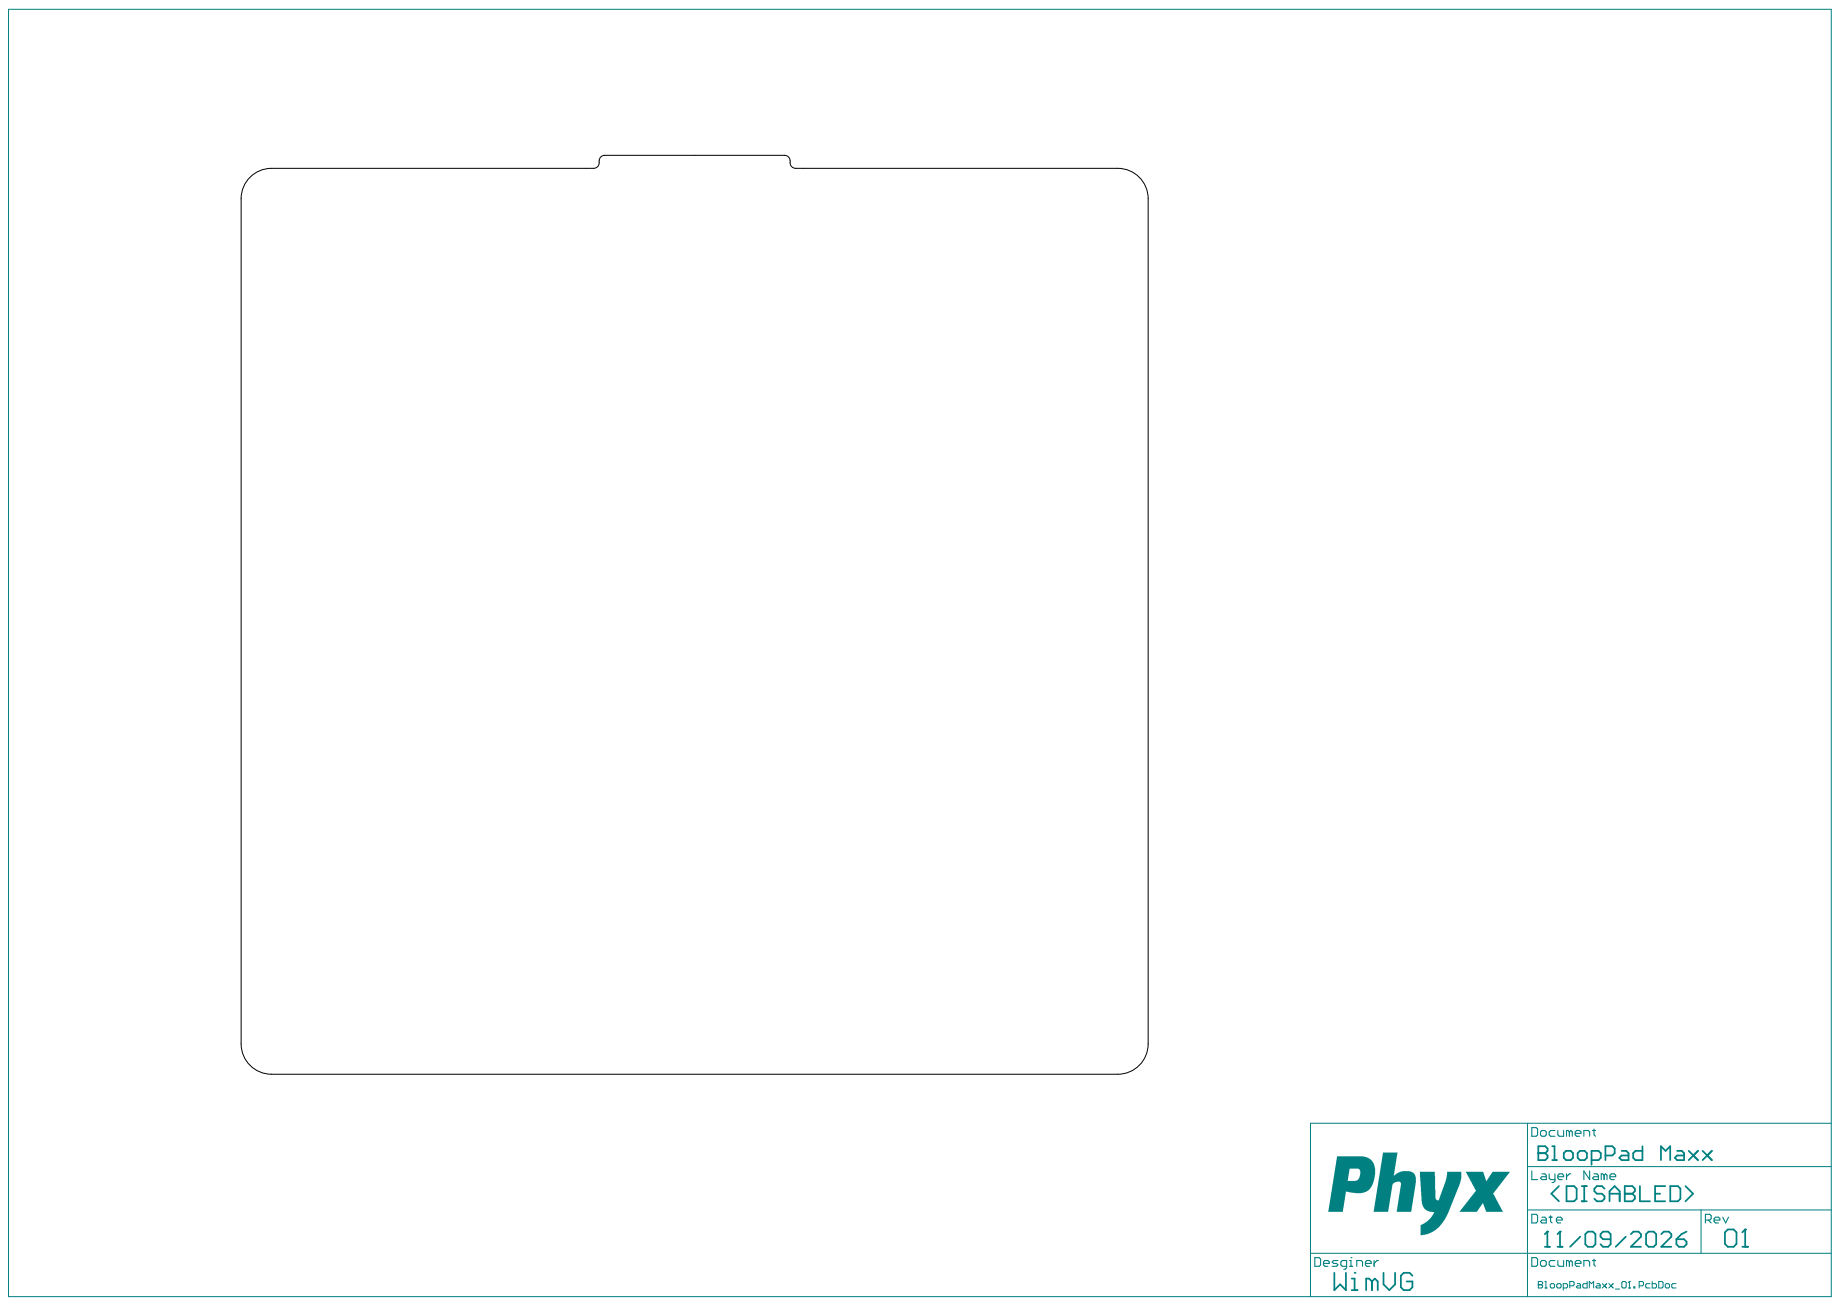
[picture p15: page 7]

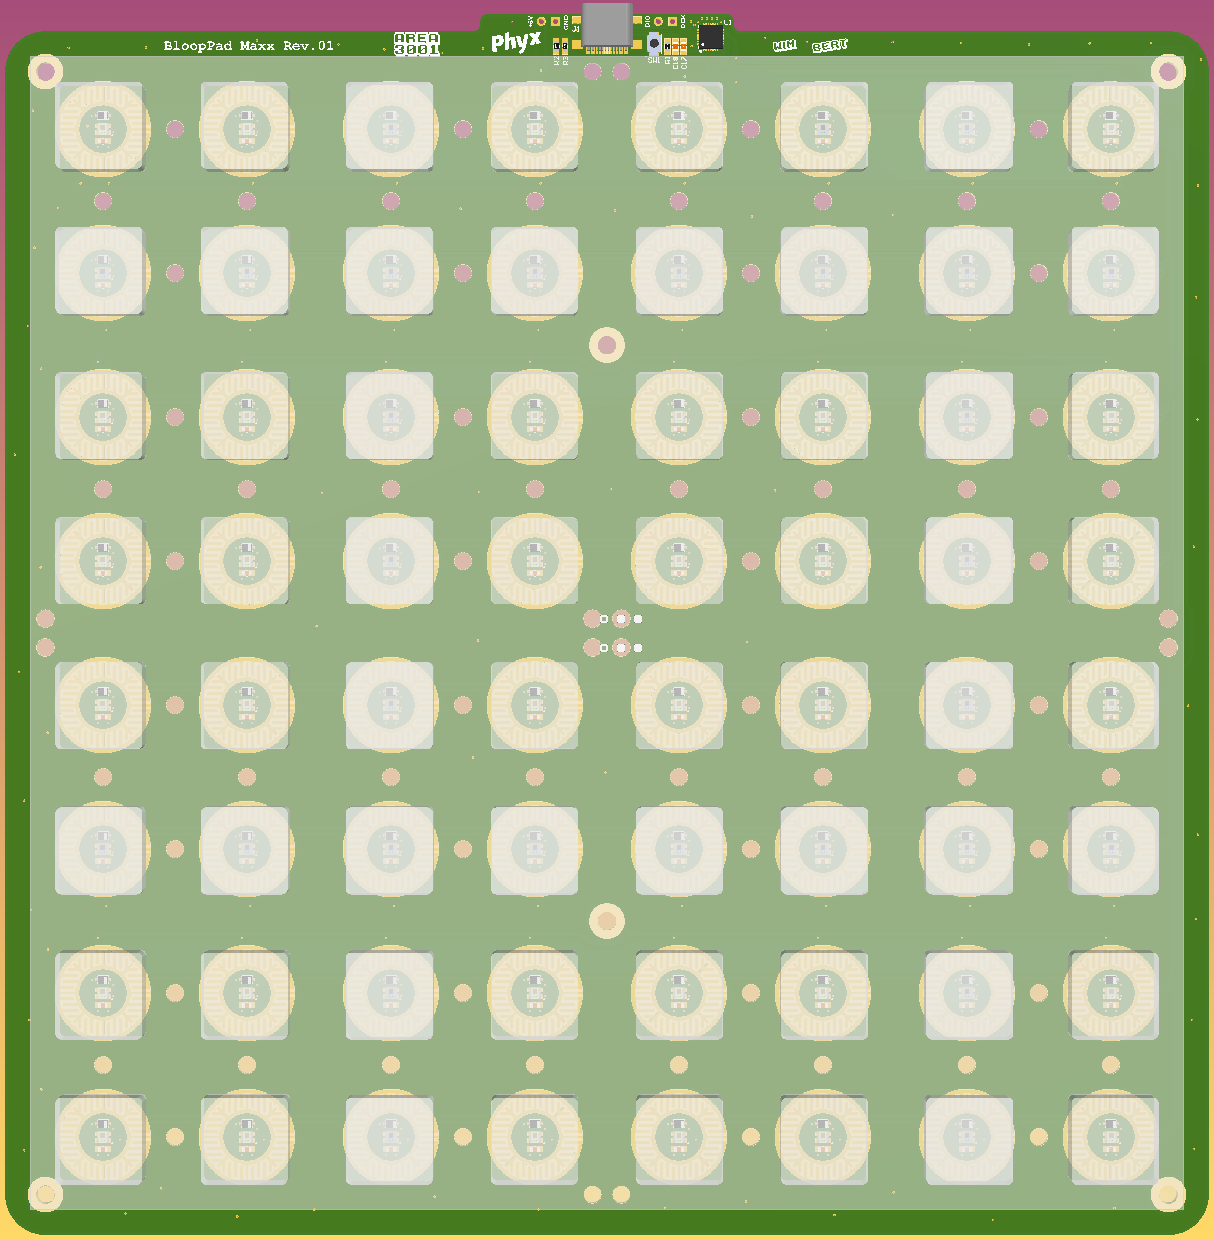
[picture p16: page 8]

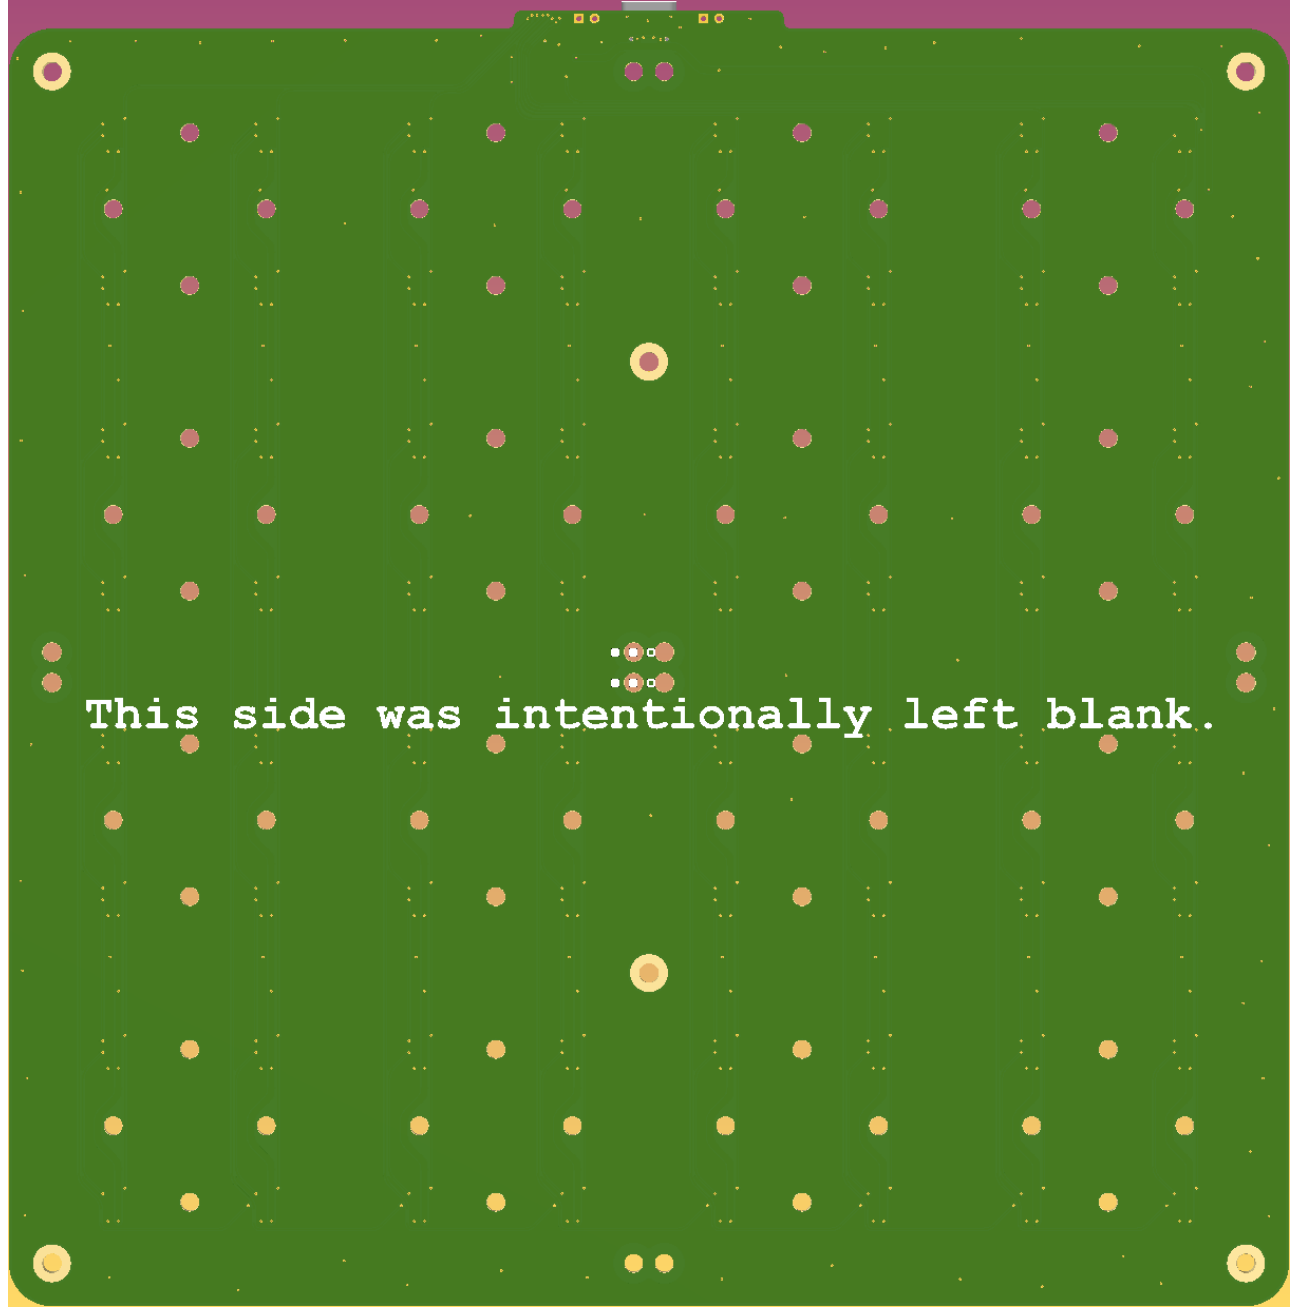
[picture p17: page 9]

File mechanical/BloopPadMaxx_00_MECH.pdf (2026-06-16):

A

B

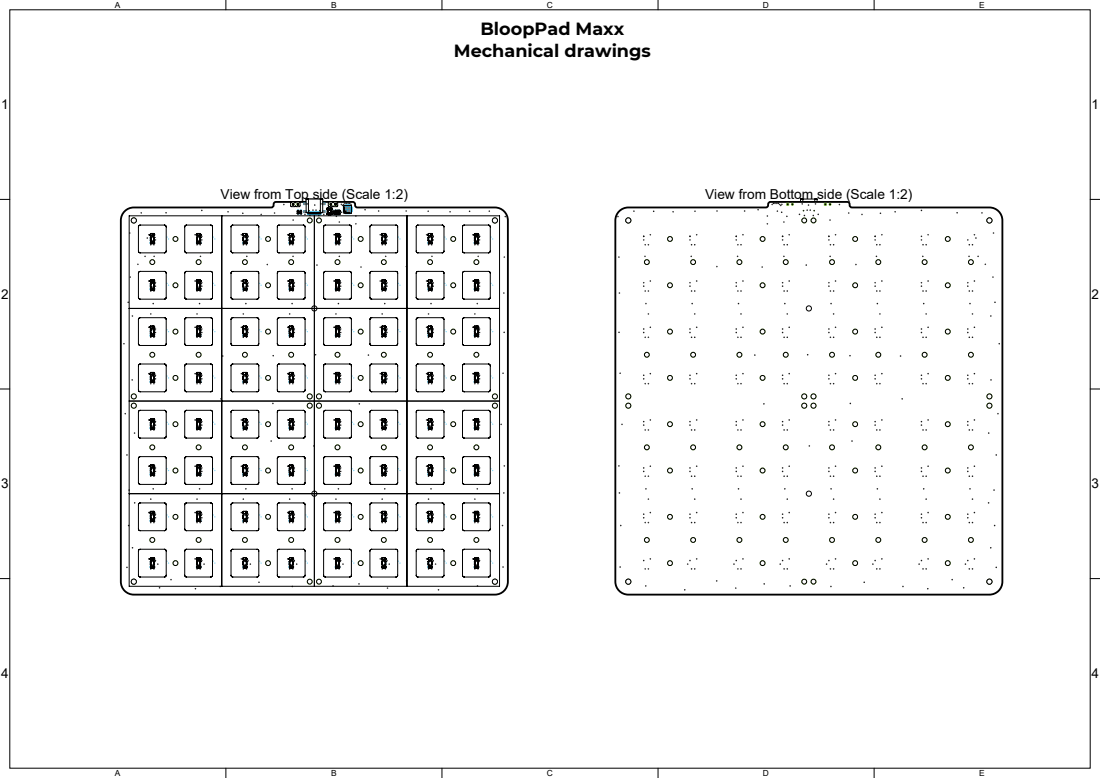
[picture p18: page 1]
View from Top side (Scale 1:2); View from Bottom side (Scale 1:2); BloopPad Maxx Mechanical drawings

A

B


View from Top side (Scale 1:2)

View from Bottom side (Scale 1:2)

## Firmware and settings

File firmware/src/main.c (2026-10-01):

#include <ch32x035.h> /* both X033 and X035 */
#include <stdlib.h>   /* atoi() */

#include <wch_usbmidi_internal.h>

/* we use our own custom debug lib */
#include "debug.h"
#include "games.h"

#define VERSION_SHOW_MS (2000) /* how long the firmware version is shown at startup */
#define MENU_COL_MIDI   (GAME_COLS - 1)
#define MENU_NONE       (0xff) /* nothing selected in the menu yet */
#define MENU_BLINK_MS   (500)  /* blink period of the selected menu button */

typedef struct
{
    void (*run)(void); /* returns when the game is over */
    const char *name;  /* scrolls by when selected */
    game_color_t color;
} menu_item_t;

/* the startup menu on the first row, indexed by column */
static const menu_item_t menu[GAME_COLS] = {
    [0] = {.run = connect_four_run, .name = "CONNECT 4", .color = {.r = 255, .g = 255, .b = 0}},
    [1] = {.run = button_masher_run, .name = "MASHER", .color = {.r = 255, .g = 0, .b = 255}},
    [2] = {.run = tug_of_war_run, .name = "TUG OF WAR", .color = {.r = 0, .g = 255, .b = 255}},
    [3] = {.run = rainbow_run, .name = "RAINBOW", .color = {.r = 0, .g = 255, .b = 0}},
    [4] = {.run = life_run, .name = "GAME OF LIFE", .color = {.r = 255, .g = 100, .b = 0}},
    [5] = {.run = tetris_run, .name = "TETRIS", .color = {.r = 255, .g = 0, .b = 0}},
    [6] = {.run = battleships_run, .name = "BATTLESHIPS", .color = {.r = 0, .g = 0, .b = 255}},
    [MENU_COL_MIDI] = {.run = midi_run, .name = "MIDI", .color = {.r = 255, .g = 255, .b = 255}},
};

static const game_color_t menu_text_color = {.r = 255, .g = 255, .b = 255};

/* the states of the startup flow */
typedef enum
{
    STARTUP_VERSION, /* show the firmware version */
    STARTUP_CHOOSE,  /* nothing selected yet, "CHOOSE GAME" scrolls by */
    STARTUP_CONFIRM, /* the selected button blinks and its name scrolls by, press it again to start it */
    STARTUP_RUN,     /* run the selected game, then back to STARTUP_CONFIRM with that game selected */
} startup_state_t;

/* show a value in binary on a single row of leds, MSB in column 0 */
static void show_binary_row(uint8_t row, uint8_t value, game_color_t color)
{
    for (int col = 0; col < GAME_COLS; col++)
    {
        if (value & GAME_BUTTON(col))
        {
            game_set_led(row, col, color);
        }
    }
}

/* show the firmware version (built from git tags via VERSION_MAJOR/MINOR/PATCH macros) in binary:
 * major on row 0 (red), minor on row 1 (green), patch on row 2 (blue)
 */
static void show_version(void)
{
    board_clear_leds();
    show_binary_row(0, atoi(VERSION_MAJOR) & 0xff, (game_color_t){.r = 255, .g = 0, .b = 0});
    show_binary_row(1, atoi(VERSION_MINOR) & 0xff, (game_color_t){.r = 0, .g = 255, .b = 0});
    show_binary_row(2, atoi(VERSION_PATCH) & 0xff, (game_color_t){.r = 0, .g = 0, .b = 255});
    board_show_leds();
    Delay_Ms(VERSION_SHOW_MS);
}

/* draw the menu on the first row and the text below it, the selected item blinks */
static void render_menu(const char *text, uint8_t selected, uint32_t elapsed_ms)
{
    game_render_text(text, elapsed_ms, menu_text_color);
    for (int col = 0; col < GAME_COLS; col++)
    {
        uint8_t blink_off = (col == selected) && (elapsed_ms % MENU_BLINK_MS) >= (MENU_BLINK_MS / 2);
        if (menu[col].run && !blink_off)
        {
            game_set_led(0, col, menu[col].color);
        }
    }
}

/* the startup flow: show the version, let the user pick a game on the first row and confirm it */
static void startup(void)
{
    startup_state_t startup_state = STARTUP_VERSION;
    uint8_t selected = MENU_NONE;
    uint32_t start = 0;
    uint8_t row;
    uint8_t col;

    while (1)
    {
        switch (startup_state)
        {
            case STARTUP_VERSION:
                show_version();
                /* buttons that are held now only count after they are released */
                game_input_reset();
                start = game_millis();
                startup_state = STARTUP_CHOOSE;
                break;

            case STARTUP_CHOOSE:
            case STARTUP_CONFIRM:
                render_menu(startup_state == STARTUP_CHOOSE ? "CHOOSE GAME" : menu[selected].name, selected, game_millis() - start);
                game_frame();
                /* the host can send SysEx commands (e.g. reboot into the bootloader) while in the menu */
                midi_poll();

                if (!game_poll_press(&row, &col) || row != 0 || !menu[col].run)
                {
                    break;
                }

                if (startup_state == STARTUP_CONFIRM && col == selected)
                {
                    startup_state = STARTUP_RUN;
                }
                else
                {
                    /* (re)select, restart the text and the blinking */
                    selected = col;
                    start = game_millis();
                    startup_state = STARTUP_CONFIRM;
                }
                break;

            case STARTUP_RUN:
                PRINT("starting %s\r\n", menu[selected].name);
                /* the moment of the press is the best source of randomness we have */
                game_seed_random(game_millis() * 2654435761u);
                menu[selected].run();

                /* the game is over: keep it selected, so one press plays it again;
                 * the button that ended the game only counts after a release
                 */
                game_input_reset();
                start = game_millis();
                startup_state = STARTUP_CONFIRM;
                break;
        }
    }
}

int main(void)
{
    SystemInit();
#ifdef NVIC_PriorityGroup_2
    NVIC_PriorityGroupConfig(NVIC_PriorityGroup_2);
#else
    NVIC_PriorityGroupConfig(NVIC_PriorityGroup_1);
#endif
    SystemCoreClockUpdate();
    Delay_Init();
    Delay_Ms(1000);

    PRINT("SystemClk: %u\r\n", (unsigned)SystemCoreClock);
    PRINT("ChipID: %08x\r\n", (unsigned)DBGMCU_GetCHIPID());

    /* initialize the LEDs and the button matrix */
    board_init();

    /* initialize USB MIDI */
    USB_init();

    PRINT("BloopPad Maxx Init done\r\n");

    startup();
}

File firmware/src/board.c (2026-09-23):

/* BloopPad Maxx hardware: the WS2812 LEDs and the button matrix */
#include <ch32x035.h> /* both X033 and X035 */
#include <string.h>   /* memset() */

#include "board.h"
#include "debug.h"

/* digital inputs: button matrix rows */
#define ROW0_PORT GPIOB /* PB12: Row 0 */
#define ROW0_PIN  GPIO_Pin_12
#define ROW1_PORT GPIOB /* PB11: Row 1 */
#define ROW1_PIN  GPIO_Pin_11
#define ROW2_PORT GPIOB /* PB10: Row 2 */
#define ROW2_PIN  GPIO_Pin_10
#define ROW3_PORT GPIOB /* PB9: Row 3 */
#define ROW3_PIN  GPIO_Pin_9
#define ROW4_PORT GPIOB /* PB8: Row 4 */
#define ROW4_PIN  GPIO_Pin_8
#define ROW5_PORT GPIOB /* PB7: Row 5 */
#define ROW5_PIN  GPIO_Pin_7
#define ROW6_PORT GPIOB /* PB6: Row 6 */
#define ROW6_PIN  GPIO_Pin_6
#define ROW7_PORT GPIOB /* PB5: Row 7 */
#define ROW7_PIN  GPIO_Pin_5
#define N_ROWS    (8)

/* digital outputs: button matrix columns */
#define COL0_PORT GPIOC /* PC0: Col 0 */
#define COL0_PIN  GPIO_Pin_0
#define COL1_PORT GPIOC /* PC3: Col 1 */
#define COL1_PIN  GPIO_Pin_3
#define COL2_PORT GPIOA /* PA0: Col 2 */
#define COL2_PIN  GPIO_Pin_0
#define COL3_PORT GPIOA /* PA1: Col 3 */
#define COL3_PIN  GPIO_Pin_1
#define COL4_PORT GPIOA /* PA2: Col 4 */
#define COL4_PIN  GPIO_Pin_2
#define COL5_PORT GPIOA /* PA3: Col 5 */
#define COL5_PIN  GPIO_Pin_3
#define COL6_PORT GPIOA /* PA4: Col 6 */
#define COL6_PIN  GPIO_Pin_4
#define COL7_PORT GPIOA /* PA5: Col 7 */
#define COL7_PIN  GPIO_Pin_5
#define N_COLS    (8)

#define TIMER_FREQ ((SystemCoreClock / 10000) - 1) /* the output frequency of all timers: 100Hz */

/* SPI1 for WS2812 LEDs */
#define LED_PORT         GPIOA /* PA7: WS2812 leds (SPI1 MOSI) */
#define LED_PIN          GPIO_Pin_7
#define LEDS_NUM         (N_ROWS * N_COLS)
#define Pixel_PRE_LEN    (12u)
#define Pixel_RESET_LEN  (25u)
#define COLOR_BUFFER_LEN (((LEDS_NUM * 3) * Pixel_PRE_LEN) + Pixel_RESET_LEN)
#define SPI1_DMA_TX_CH   DMA1_Channel3

typedef struct
{
    uint8_t g; /* Green */
    uint8_t r; /* Red */
    uint8_t b; /* Blue */
} ws2812b_color_t;

typedef struct
{
    uint8_t matrix_state[N_COLS];   /* button state bytes, written by the matrix scan interrupt */
    ws2812b_color_t leds[LEDS_NUM]; /* LED data */
} board_state_t;

static board_state_t state;

/* buffer to hold the SPI data for WS2812 */
static uint8_t color_buf[COLOR_BUFFER_LEN] = {0};

/* WS2812 LEDs use a 1-wire protocol where a '1' bit is a ~0.8µs high pulse and
 * a '0' bit is a ~0.4µs high pulse. We drive the data line via SPI at ~6 MHz
 * (one SPI bit ≈ 167 ns), which means each WS2812 bit maps to 4 SPI bits:
 *   WS2812 '1' → 1110 (0xE in a nibble)
 *   WS2812 '0' → 1000 (0x8 in a nibble)
 * Two WS2812 bits are packed into one SPI byte, so each LED color byte (8 bits)
 * expands to 4 SPI bytes.  Three color channels (GRB order) → 12 SPI bytes per LED
 * (Pixel_PRE_LEN = 12). The reset pulse is at least 50µs of low; Pixel_RESET_LEN
 * zero-bytes pad the end of the DMA buffer.
 */

/*********************************************************************
 * @fn      convToBit
 *
 * @brief   Encode one byte of WS2812 color data into 4 SPI bytes.
 *          Each input bit becomes a nibble: 0xE for a '1', 0x8 for a '0'.
 *          Two nibbles are packed per output byte, MSB first.
 *
 * @param   res   - output buffer (must have room for 4 bytes)
 *          input - color channel byte to encode
 *
 * @return  none
 */
static void convToBit(uint8_t *res, uint8_t input)
{
    uint8_t mask = 0x80;
    for (int i = 0; i < 4; i++)
    {
        uint8_t result = (input & mask) ? 0xE : 0x8;
        result <<= 4;
        mask >>= 1;
        result |= (input & mask) ? 0xE : 0x8;
        mask >>= 1;
        res[i] = result;
    }
}

/*********************************************************************
 * @fn      colorToBit
 *
 * @brief   Convert color to spi bit
 *
 * @param   buf  - the result
 *          r  - red channel
 *          g  - green channel
 *          b  - blue channel
 *
 * @return  none
 */
static void colorToBit(uint8_t *buf, uint8_t r, uint8_t g, uint8_t b)
{
    uint8_t *res = buf;
    convToBit(res, g);
    convToBit(&(res[4]), r);
    convToBit(&(res[8]), b);
}

/*********************************************************************
 * @fn      setPixelColor
 *
 * @brief   Set the pixel color of an LED
 *
 * @param   index - index of LED
 *          r  - red channel
 *          g  - green channel
 *          b  - blue channel
 *
 *
 * @return  none
 */
static void setPixelColor(uint16_t index, uint8_t r, uint8_t g, uint8_t b)
{
    uint8_t *buf = &(color_buf[index * Pixel_PRE_LEN]);
    colorToBit(buf, r, g, b);
}
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

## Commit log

2026-06-16 fix I2C slave
2026-06-16 fix the UART MIDI receive loop
    [main.c]
2026-06-16 improve the README.md and updated LED handling
2026-06-16 fix invalid MIDI CC numbers
    [main.c]
2026-06-16 cleanup and fix the indexing
    [main.c]
2026-06-16 added hardware design and production files
    [BloopPadMaxx_00.GBL, BloopPadMaxx_00.GBO, BloopPadMaxx_00.GBP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]
2026-06-16 fix button layout
2026-06-16 fix LED indexing
2026-06-17 add full LED control using MIDI SysEx messages
2026-08-12 remove prints from interrupt handler and fix i2c write
    [main.c]
2026-08-26 fix repeated last MIDI message
    [main.c]
2026-08-27 fix sysex bounds check
    [main.c]
2026-08-28 encode the firmware version in the serial number of the USB device
2026-09-02 request more USB power
2026-09-23 add bottom rubber laser cut svg and bottom cover svg
2026-09-24 add LED animations game
2026-10-01 Reboot into the ISP bootloader on a SysEx command
    Reflashing needs the boot button held while USB is replugged, which means the
    pad has to be physically reachable and the host has to be told to wait. The pad
    can do it itself: this adds one reserved SysEx message that puts it into WCH's
    ISP bootloader, so a host can reflash with nothing held and nothing unplugged.
    F0 13 37 00 42 4F 4F F7
    The 0x00 is where an LED frame carries its first index, and 0x00 is never a valid
    index - an address byte's low nibble is always 8-15 - so the two cannot be
    confused, and firmware without this change ignores the message rather than
    painting anything. The trailing 42 4F 4F ("BOO") makes it a deliberate e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
2026-10-01 Share the USB-MIDI packet dissection instead of duplicating it
    Review comment: bootloader.c duplicated the SysEx parsing from game_midi.c. It
    did, in two ways - its own copy of the Code Index Number table, and its own switch
    mapping a CIN to the number of SysEx bytes that packet carries. Both now live in
    midi_packet.{c,h}, with midi_sysex_byte_count() owning the mapping.
    bootloader.c loses the defines and the switch and becomes a count-and-loop.
    game_midi.c loses the duplicated constants too, and its four SysEx cases now ask
    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
2026-10-01 Handle the bootloader SysEx in game_midi.c instead of a separate module
    Rework of the previous two commits. The bootloader request is now
    recognized in handle_midi()'s existing SysEx path (finalize_sysex()), so
    bootloader.c/.h and midi_packet.c/.h are removed again.
    A new midi_poll() in game_midi.c handles all available USB-MIDI packets
    and returns; the game menu calls it every frame, replacing the drain in
    game_frame(). The command therefore works in the game menu and in MIDI
    mode, not while a game is running. midi_poll() and midi_run() only read
    complete 4-byte packets and drain everything that is available.
    The README's bootloader section is updated to say where the command
    works and th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
    [main.c]
2026-10-01 3D printable enclosure which takes M2.5 threaded inserts
    [BloopPadMaxx_00_inserts.step]
2026-10-03 Rev.01 design and production files added
    [BloopPadMaxx_01.GBL, BloopPadMaxx_01.GBO, BloopPadMaxx_01.GBP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]
2026-10-17 Add 8 new games: Othello, Minesweeper, Lights Out, Mastermind, Paddle duel, Whack-a-mole, Rhythm tap and Finger twister
    Othello plays reversi on the full board against the computer or a second
    player, with positional-weight AI on hard. Minesweeper uses a short press
    to reveal and a hold to flag, with a safe first reveal. Lights Out is
    scrambled from the solved state so every puzzle is solvable. Mastermind
    builds guesses on the bottom row and shows bright/dim feedback pegs.
    Paddle duel and Finger twister lean on the n-key rollover of the matrix:
    hold edge buttons as a paddle, or hold every lit button at once. Rhythm
    tap judges presses by the distance of the racing light to the target.
    Single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
2026-10-17 Show the new games as colored buttons on the bottom row of the menu
    The menu now has room for 16 modes: the original games on the top row,
    the new games plus MIDI on the bottom row. Press once to select, again
    to start, on either row.
2026-10-17 Add ready-to-print top cover files with insert holes
    An STL export of the printable top cover that takes the M2.5 threaded
    inserts, plus a 3MF sliced for a Bambu Lab P1S (0.4 nozzle, 0.12 mm
    layers) so it can be sent straight to the printer.
2026-10-19 Add printable bottom plate (STL + OBJ) with M2 countersunk screw holes
    Matches the BloopPadMaxx_00_inserts design. OBJ ships with its MTL.
